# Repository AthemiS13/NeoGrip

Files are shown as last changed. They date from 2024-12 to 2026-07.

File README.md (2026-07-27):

# NeoGrip
Affordable custom controllers for Quest 2 and other VR headsets **purchased without original controllers**, or for those looking for open-source VR controllers. Designed using **ESP32** and [ALVR's API](https://github.com/alvr-org/ALVR "ALVR API") to emulate Quest controllers in **SteamVR**, this project makes headsets without controllers usable and accessible for VR enthusiasts on a budget.

> **Note:** The full, comprehensive documentation for this project is located in [Assets/dokumentace.pdf](Assets/dokumentace.pdf). Unfortunately, it is currently only available in the Czech language.

NeoGrip animation

## Motivation & Goals
The VR equipment market has a paradox: second-hand headsets like Meta Quest are very affordable, but they are often sold without original controllers, which are either unavailable or excessively expensive. NeoGrip was created to break this barrier, utilizing the hidden potential of incomplete VR setups. The goal is to provide a fully functional, open-source hardware and software solution that bridges the physical environment with SteamVR through affordable components.

## Hardware Requirements (Bill of Materials)
- **ESP32** Dev Module [Link](https://www.aliexpress.com/item/1005004879572949.html "Link")
- **TP4056** Charging Module [Link](https://www.aliexpress.com/item/1005007010409267.html "Link")
- **Joystick** KY-023 module [Link](https://www.aliexpress.com/item/1005006966359366.html "Link")
- **Buttons** (A, B, X, Y, Menu, Oculus) [Link](https://www.aliexpress.com/item/1005004254514071.html "Link")
- **End switches** Grab and Trigger (KW11-3Z-4-N) [Link](https://www.aliexpress.com/item/1005006260069918.html "Link")
- 3D-printed controller **parts** (STEP files available [here](https://github.com/AthemiS13/NeoGrip/tree/main/STEP-Files "here"))
 - **Regulator** Ultra Low Dropout voltage, 3.3V (RT9183-33GGF)
 - **Battery** 3.7V, 500mAh, Li-Po (You might be able to fit a bigger one) [Link](https://www.aliexpress.com/item/1005003156469047.html "Link")
  - **Transistor** Generic PNP or NPN transistor for haptic motor control.
  - **Haptic** Motor, 3.3V [Link](https://www.aliexpress.com/item/1005007550657082.html "Link")
  - **Screws, Springs, 2mm Shaft, Wires** 

## Hardware Design & Architecture
NeoGrip is designed with ergonomics and functionality mirroring the Meta Quest 2/3 controllers:
- **Core Controller:** ESP32 Dev Module (Dual-core Xtensa LX6 240MHz, Wi-Fi 2.4GHz) for minimal latency and high performance.
- **Controls:** Standard microswitches (A/X, B/Y, System, Joystick Click), highly reliable end switches KW11-3Z for Trigger and Grip (translated to 0.0/1.0 analog values for OpenXR), and KY-023 analog joysticks for X/Y movement.
- **Haptic Feedback:** Embedded 3.3V vibration motor driven by PWM via a PNP transistor for tactile responses from SteamVR.
- **Power Management:** Powered by a 3.7V 500mAh Li-Po battery providing ~6 hours of active playtime. Protected and charged via a TP4056 module (USB-C or Micro-USB). Includes an automatic deep sleep mode after 60 seconds of inactivity to save power, easily wakeable via the System button. An LDO RT9183 regulator provides stable 3.3V.

## Software Requirements
- [NeoGrip Proxy for Windows](https://github.com/AthemiS13/NeoGrip/releases) (download the latest `NeoGrip-Proxy.exe` release)
- [ALVR](https://github.com/alvr-org/ALVR "ALVR")
- [Arduino IDE](https://www.arduino.cc/en/software "Arduino IDE") or compatible ESP32 programming environment
- SteamVR
### Notes on Quest 2 Setup:
If you have purchased a Quest 2 without controllers that is logged out and factory resetted, bypassing the **initial setup** can be challenging. While this README focuses on the VRController project, instructions for bypassing the setup to enable hand tracking and unlock the headset can be provided on request.

## Software setup
### NeoGrip Proxy setup:
1. Go to the [latest NeoGrip release](https://github.com/AthemiS13/NeoGrip/releases) and download `NeoGrip-Proxy.exe`.
2. Start ALVR on the PC that will run the proxy.
3. Run `NeoGrip-Proxy.exe` and leave its console window open during your VR session.
4. Press the **System** button on each NeoGrip controller to connect it.

The proxy receives controller input on UDP port `9999`, sends haptic feedback on UDP port `8888`, and must be on the same local Wi-Fi network as the controllers.

> Windows SmartScreen may show a warning because the executable is not code-signed. If you downloaded it from the official NeoGrip GitHub release, select **More info** and then **Run anyway**.
### Pin Mapping (Right Controller Example)
- `GPIO 4`: System Button / Deep Sleep Wake (RTC GPIO)
- `GPIO 14`: Joystick Click
- `GPIO 16`: PWM Motor Output
- `GPIO 18`: B Button
- `GPIO 19`: Trigger (KW11-3Z)
- `GPIO 21`: A Button
- `GPIO 27`: Squeeze/Grip (KW11-3Z)
- `GPIO 34`: Joystick X-Axis (ADC 0-4095)
- `GPIO 35`: Joystick Y-Axis (ADC 0-4095)

### 3D Printed Chassis
Designed in Autodesk Fusion 360, printable via FDM. Recommended settings:
- **Material:** PLA (PETG optional for more durable triggers).
- **Layer Height:** 0.2mm for the main body, 0.15mm for finer button details.
- **Infill:** 65% Gyroid for high structural integrity and low weight.
- **Temperature:** 210°C for optimal layer adhesion.
- **Supports:** Tree-type supports recommended.

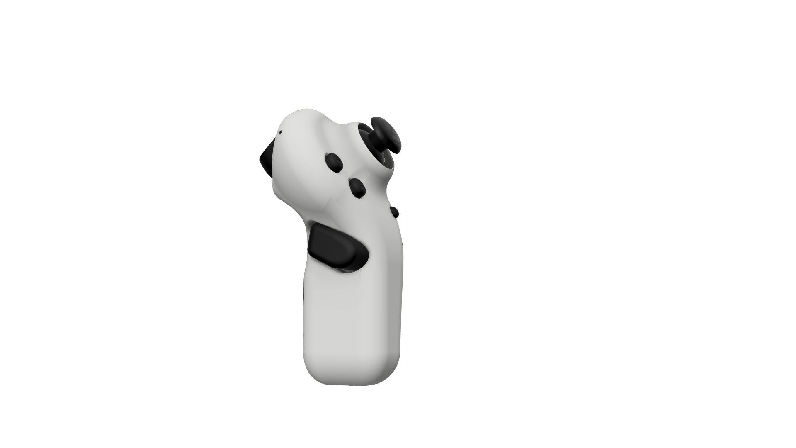
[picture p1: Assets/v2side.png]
Side


## How it Works
The architecture consists of the ESP32 hardware and a multi-threaded Python-based proxy server on the PC.

### 1. ESP32 Input Processing
Every 40ms, the ESP32 reads analog and digital inputs and formats them into a lightweight 15-character UDP broadcast packet (e.g., `L00010204720470`):
- **Char 1:** Side identifier (`L` or `R`).
- **Chars 2-6:** Button states (`A/X`, `B/Y`, `SYS`, `Trigger`, `Grip`) as `0` or `1`.
- **Chars 7-10:** Joystick X-axis analog value (`0000`-`4095`).
- **Chars 11-14:** Joystick Y-axis analog value (`0000`-`4095`).
- **Char 15:** Joystick Click state (`0` or `1`).

### 2. Python Proxy Server (`NeoGrip.py`)
To prevent blocking, the proxy server uses multiple threads:
- **Main Thread:** Receives UDP packets from the ESP32 on port `9999`.
- **ALVR Thread:** Forwards processed controller data to ALVR's REST API (`POST http://127.0.0.1:8082/api/set-buttons`).
- **WebSocket Thread:** Listens to `ws://localhost:8082/api/events` for haptic feedback triggers from SteamVR.
- **Start Signal Thread:** Broadcasts a "START" UDP packet to wake controllers from deep sleep.

### 3. ALVR and SteamVR Integration
The proxy translates raw values into standardized OpenXR paths (e.g., `/user/hand/left/input/trigger/value`), allowing the controllers to work natively with SteamVR. Instead of built-in positional tracking, the project relies on **Meta Quest Hand Tracking**. SteamVR binds the controller inputs directly onto the tracked hands in VR.

### 4. Haptic Feedback
The WebSocket thread captures haptic events, parsing the target controller (path), vibration duration, and amplitude. It maps amplitude (0.0-1.0) to PWM duty cycles (0-255) and converts the duration to milliseconds. It then sends a 7-character UDP packet back to the ESP32 on port `8888` (e.g., `R255100` -> Right controller, 255 duty cycle, 100ms duration).

### ALVR Configuration
For ALVR to accept inputs from the proxy server and track the controllers properly via headset cameras, you must adjust the following settings in ALVR:
1. **Presets tab:** Turn **off** "Hand tracking interaction" (we want to use the controller buttons, not gesture interactions).
2. **Headset tab:** Ensure the following are **enabled/on**:
   - `Controllers`
   - `Tracked`
   - `Multimodal tracking`
   - `Haptics`
3. Ensure that "SteamVR Input 2.0" and "Hand tracking interaction" (under Headset) are disabled.

> **Note:** A detailed visual guide for the ALVR configuration, alongside screenshots, is available in the [documentation PDF](Assets/dokumentace.pdf) as well as in the [Config](Config) directory.

### Running the System
1. Start SteamVR and ALVR. Verify configuration.
2. Run the proxy server via terminal:
   ```bash
   python NeoGrip.py
   ```
   The terminal will indicate that it's broadcasting the "START" signal.
3. Press the **System** button on your NeoGrip controllers to wake them up. They will connect to Wi-Fi and vibrate briefly upon a successful connection.
4. Put on your headset. Your controllers are now ready to use in SteamVR!
5. To stop, press `Ctrl+C` in the proxy console. The proxy will send a "STOP" signal, putting the controllers back to deep sleep.

## Performance & Testing
- **Latency:** The system provides extremely low latency, averaging under 50ms from physical button press to VR action, which is well within comfortable limits for fast-paced VR games.
- **Reliability:** The 2.4GHz Wi-Fi UDP connection provides robust data transmission with negligible packet loss (<1%). Missing packets are instantly superseded by the 25Hz refresh rate.
- **Battery Life:** ~6 hours of continuous playtime. The TP4056 module charges the 500mAh Li-Po battery at a rate of 1A, allowing a full recharge from 0 to 100% in approximately 45 minutes.

## Videos

### Finished Product Showcase
[**Watch the NeoGrip Finished Product Showcase on YouTube**](https://www.youtube.com/watch?v=nmFFR0dLkeE)

Watch the NeoGrip Finished Product Showcase (https://www.youtube.com/watch?v=nmFFR0dLkeE)

### 2024 Demo
[**Watch the NeoGrip 2024 Demo on YouTube**](https://youtu.be/AhS3Zu6njnE?si=yEACRPgUvw43rx8U)
Watch the video (https://youtu.be/AhS3Zu6njnE?si=yEACRPgUvw43rx8U)

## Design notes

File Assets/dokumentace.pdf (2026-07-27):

## Gymnázium a Jazyková škola s právem státní jazykové zkoušky Zlín

# NeoGrip

## Vývoj softwarového proxy serveru pro integraci alternativního hardwaru do platformy SteamVR

### Jakub Chmelař

2026

# Poděkování

Tímto bych rád upřímně poděkoval svému pedagogovi, panu učiteli Michalovi Miklášovi, za obětavou pomoc, cenné konzultace a významné prohloubení mých vědomostí v programovacím jazyce Python, které byly pro zdárné dokončení této práce klíčové. Dále bych chtěl vyjádřit své poděkování komunitě vývojářů softwaru ALVR za jejich vstřícnost a skvělou spolupráci v průběhu celého vývoje projektu.

# Anotace

Tato práce se detailně zabývá návrhem a implementací projektu NeoGrip. Cílem systému je vytvořit funkční spojovací článek mezi hardwarovými ovladači, postavenými na mikrokontroleru ESP32, a prostředím virtuální reality SteamVR. Pro distribuci vstupů a přenos prostorových dat je využíván otevřený software ALVR. Ačkoliv projekt zahrnuje i konstrukci fyzického elektronického obvodu, primární pozornost a stěžejní téma této práce tvoří softwarová vrstva. Jejím jádrem je návrh a vývoj vlastního proxy serveru vybudovaného v jazyce Python. Právě tento programovací blok představuje ústřední prvek řešení, který získává nezpracovaná data uživatelského hardwaru a v reálném čase je transformuje do rozhraní virtuálního prostředí.

# Klíčová slova

virtuální realita; SteamVR; ESP32; proxy server; ALVR; Python; hardware

# Obsah

Seznam obrázků | 5
Seznam tabulek | 6
1 Úvod | 7
2 Motivace a cíle projektu | 8
3 Teoretická východiska | 9
4 Hardwarový návrh | 11
5 Činnost a logika mikrokontroleru ESP32 | 15
6 Softwarová vrstva (proxy server) | 18
7 Integrace se softwarem ALVR a platformou SteamVR | 23

8 Instalace a spuštění | 28
9 Testování a výsledky | 30
10 Závěr | 33
Bibliografie | 34

# Seznam obrázků

1 | Pohled na ovladač NeoGrip ze strany | | 7

2 Vývojová deska s mikrokontrolerem ESP32 | 10 3 Schéma rozložení pinů ESP32 DevKit V1 | 11 4 Vnitřní uspořádání elektronických komponent v programu Fusion 360 . . . 12 5 Detail ovladače NeoGrip s viditelnými ovládacími prvky | 13 6 Návrh celého ovladače NeoGrip v programu Fusion 360 | 14 7 Model hlavního těla ovladače připravený pro 3D tisk | 15 8 Pohled na zadní stranu ovladače NeoGrip | 15 9 Krok 1: Nastavení v záložce Presets | 25 10 Krok 2: Nastavení v záložce Headset | 26 11 Krok 3: Dodatečné konfigurace | 27

# Seznam tabulek

### 1 Přiřazení pinů mikrokontroleru ESP32 (pravý ovladač) | 12 2 Formát odesílaného UDP paketu | 16 3 Přehled vláken proxy serveru | 18

4 | Proces zpracování haptické zprávy z ALVR | | 21

### 5 Vstupní cesty ALVR API (levý ovladač) | 24

# 1 Úvod

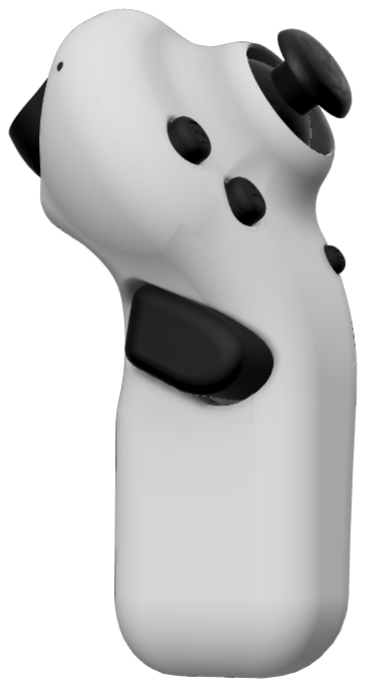
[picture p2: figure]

obrázek 1: Pohled na ovladač NeoGrip ze strany

Projekt NeoGrip představuje inovativní architekturu, jež prostřednictvím proxy serveru napsaného v jazyce Python efektivně propojuje cenově dostupný mikrokontroler ESP32 se systémem SteamVR. Ačkoliv je pro komplexní pochopení problematiky nutné v práci představit všechny vrstvy tohoto fungujícího celku, hlavním těžištěm textu a primárním zaměřením je vývoj zmíněného proxy serveru v jazyce Python. Plynulý a spolehlivý tok dat zajišťuje integrace softwarového nástroje ALVR, což otevírá nové možnosti alternativního řízení a ovládání ve virtuálním prostředí.
Trh s periferními zařízeními pro virtuální realitu je velmi omezený: zatímco náhlavní soupravy jsou stále dostupnější, ceny originálních ovladačů zůstávají nepřiměřeně vysoké nebo jsou tyto periferie zcela nedostupné. Projekt NeoGrip si klade za cíl tuto bariéru odstranit cestou otevřeného hardwarového a softwarového řešení postaveného na všeobecně dostupných komponentech.
Dokument je strukturován tak, aby čtenáře systematicky provedl od hardwarového návrhu přes firmwarovou implementaci až ke klíčové softwarové vrstvě. Závěrečné kapitoly pak popisují integraci s ekosystémem ALVR a SteamVR, postup instalace a výsledky praktického testování.

# 2 Motivace a cíle projektu

## 2.1 Problém dostupnosti VR ovladačů

Současný trh s vybavením pro virtuální realitu se potýká se zajímavým paradoxem. Náhlavní soupravy z druhé ruky, jako je populární rodina Meta Quest, lze pořídit za velmi příznivé ceny. Jejich zásadním úskalím je nicméně to, že se často prodávají samotné, tedy bez originálních ovladačů. Samostatné originální ovladače jsou buď zcela nedostupné, nebo jejich pořizovací cena výrazně převyšuje hodnotu samotné soupravy. Mnoho uživatelů se tak dostává do slepé uličky, kdy levnou a zcela funkční soupravu nemohou používat ke svému primárnímu účelu.
Hlavní motivací tohoto projektu bylo odstranit tuto bariéru a využít skrytý potenciál nekompletních souprav pro virtuální realitu. Cílem bylo navrhnout, sestavit a naprogramovat cenově dostupné hardwarové ovladače s otevřeným designem ve formátu zařízení Meta Quest 2, jež by propojily fyzické prostředí s prostředím virtuálním prostřednictvím systému SteamVR.

## 2.2 Cíle projektu

Během realizace byly sledovány následující cíle:

- Přístupná hardwarová architektura: Navrhnout logický obvod s mikrokontrolerem ESP32 jako klíčovou řídicí jednotkou. Architektura měla obsahovat všechny ovládací prvky původní periferie Meta Quest 2 (analogové páčky s proklikem, přední a boční tlačítka, haptická odezva). Nedílnou součástí je také efektivní správa napájení zajištěná integrovaným obvodem TP4056 a implementace režimu hlubokého spánku při nečinnosti.
- Proxy server: Vytvořit stabilní softwarový můstek zprostředkující datový převod zasílaných stisků a analogových hodnot z ESP32 odesílaných bezdrátově skrze protokol UDP směrem do SteamVR.
- Integrace s ALVR: Pro převod nezpracovaných dat do systémových akcí rozeznatelných ekosystémem SteamVR bylo nutné využít aplikační rozhraní projektu ALVR. Zprostředkující proxy server v jazyce Python tak slouží jako neviditelná vrstva tvořící softwarový klíč pro danou architekturu.

## 2.3 Přínos a uplatnění projektu

Jak ukáže technická sekce maturitní práce o vývoji NeoGripu, spojení hardwarového obvodu ovládaného platformou ESP32 a softwarového překladače dat se ukázalo jako velice úspěšné a vysoce uplatnitelné řešení. Výsledný systém je plně funkční, jeho celkové náklady na výrobu jednoho páru ovladačů nepřesahují 600 Kˇc, a veškerý zdrojový kód spolu s výkresovou dokumentací je volně dostupný jako otevřený projekt[8].

# 3 Teoretická východiska

## 3.1 Virtuální realita a její ekosystém

Virtuální realita (VR) je technologie umožňující uživateli plné ponoření do počítačem generovaného trojrozměrného prostředí prostřednictvím náhlavní soupravy. Klíčovými vlastnostmi moderní virtuální reality jsou sledování polohy hlavy v šesti stupních volnosti¹ ,
prostorový zvuk a interakce prostřednictvím ručních ovladačů snímajících pohyb a stisk tlačítek.

## 3.2 Platforma SteamVR a standard OpenXR

SteamVR je softwarová platforma společnosti Valve Corporation, jež tvoří standardizovaný mezičlánek mezi VR aplikacemi a hardwarem různých výrobců. SteamVR implementuje standard OpenXR[4]²
, jenž zavádí jednotný způsob popisu vstupů ovladačů pomocí cest. Například cesta /user/hand/left/input/trigger/value jednoznačně identifikuje analogovou hodnotu spouště levého ovladače.
Pro projekt NeoGrip je tato vrstva zásadní: díky standardizovanému popisu vstupů lze vlastní firmwarová data přeložit do formátu srozumitelného pro libovolnou VR aplikaci kompatibilní s SteamVR, aniž by bylo nutné upravovat samotné herní tituly.

## 3.3 Software ALVR

ALVR (Air Light VR) je otevřený software, jenž zprostředkovává bezdrátový přenos VR obrazového toku z osobního počítače do mobilní náhlavní soupravy na platformě Android. V kontextu tohoto projektu do zařízení Meta Quest 2.[1]
Kromě přenosu obrazu disponuje ALVR aplikačním rozhraním:
- REST API naslouchající na portu 8082, přes které lze vkládat vstupní události ovladačů metodou POST na koncový bod /api/set-buttons.
- WebSocket na adrese ws://localhost:8082/api/events, přes který ALVR v reálném čase vysílá události haptické odezvy pocházející z SteamVR.

Tato dvě rozhraní tvoří základ obousměrné komunikace projektu NeoGrip s ekosystémem SteamVR a jsou podrobněji popsána v kapitole 7.

## 3.4 Komunikační protokol UDP

Pro přenos dat mezi ovladačem ESP32 a proxy serverem byl zvolen protokol UDP[11]. Na rozdíl od protokolu TCP nezaručuje UDP doručení každého paketu ani jejich pořadí,

1Šest stupňů volnosti (anglicky six degrees of freedom, zkr. 6DoF) označuje kombinaci tří translačních (posun v osách X, Y, Z) a tří rotačních pohybů, které je systém schopen sledovat v reálném čase. 2OpenXR je otevřený mezioborový standard definovaný společností Khronos Group, který sjednocuje aplikační rozhraní pro vývoj VR a rozšířené reality (AR).

avšak jeho klíčovou předností je minimální latence způsobená absencí potvrzovacích mechanismů.[3] V kontextu ovladače pro virtuální realitu, kde je okamžitá odezva nadřazena absolutní spolehlivosti přenosu, představuje volba protokolu UDP optimální kompromis. Ztráta ojedinělého paketu způsobí pouze krátkodobé zdržení a je automaticky překryta dalším paketem přijatým po 40 ms.

## 3.5 Mikrokontroler ESP32

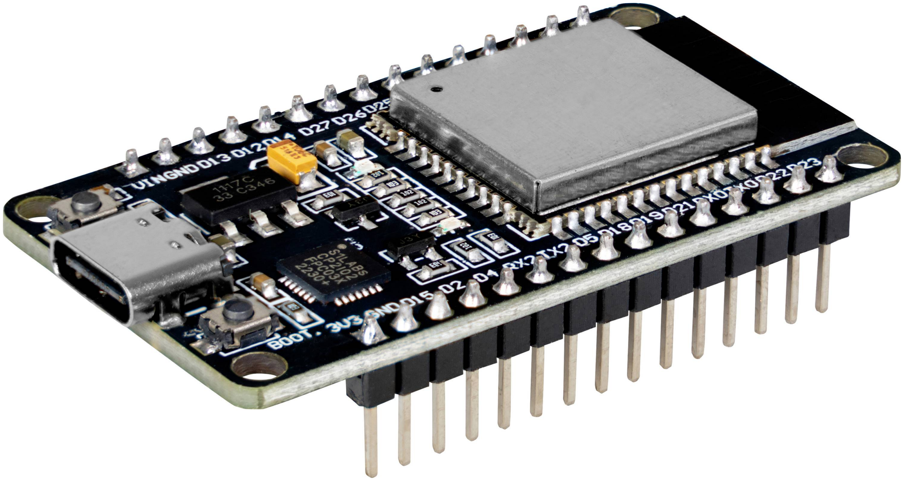
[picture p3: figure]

obrázek 2: Vývojová deska s mikrokontrolerem ESP32

ESP32 je rodina systémů na čipu vyvinutá společností Espressif Systems.[2] Klíčovými vlastnostmi relevantními pro tento projekt jsou:

- dvoujádrový procesor Xtensa LX6 s taktovací frekvencí až 240 MHz,
- integrovaný Wi-Fi modul standardu 802.11 b/g/n v pásmu 2.4 GHz,
- dvanáctibitový analogově-digitální převodník (ADC) s rozsahem 0 až 4095 pro snímání analogových hodnot páčky,
- podpora pulzně-šířkové modulace (PWM)[14] pro řízení haptického motoru,
- režim hlubokého spánku s příkonem řádově v jednotkách µA.

# 4 Hardwarový návrh

Realizace fyzického ovladače vyžadovala pečlivý výběr komponent, které by splňovaly přísné požadavky na minimální odezvu, dostatečný výpočetní výkon pro zpracování síťového provozu a zároveň udržely celkové pořizovací náklady na rozumném minimu. Rozložení ovládacích prvků navíc přímo vychází z ergonomie a architektury ovladačů Meta Quest 2, čímž je zaručena pro uživatele intuitivní ovladatelnost.

## 4.1 Řídicí jednotka ESP32

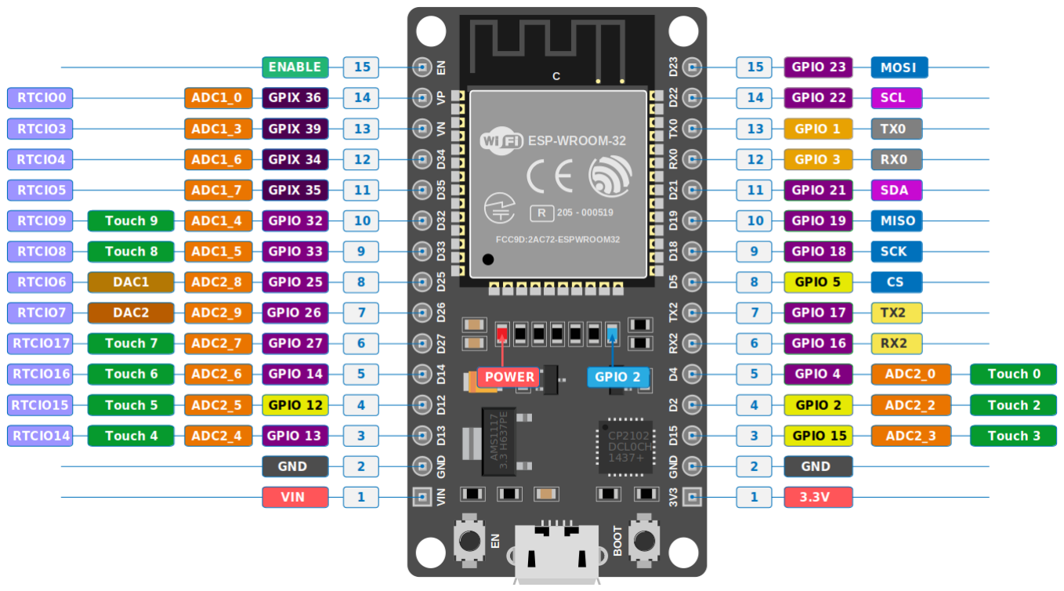
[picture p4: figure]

obrázek 3: Schéma rozložení pinů ESP32 DevKit V1

Jako řídicí mozek celého ovladače byl zvolen mikrokontroler ESP32 ve verzi Dev Module. Tato platforma se vyznačuje vysokým výkonem (dvoujádrový procesor) a především integrovaným Wi-Fi modulem pracujícím v pásmu 2.4 GHz. Přítomnost Wi-Fi adaptéru je kritická, jelikož veškerá data o stisku tlačítek a hodnotách analogových páček jsou z ESP32 odesílána vzduchem prostřednictvím rychlého protokolu UDP do nadřazeného proxy serveru na osobním počítači (v neměnném intervalu 40 ms).
Přiřazení vstupních a výstupních pinů mikrokontroleru pro pravý ovladač je shrnuto v tabulce 1.

## 4.2 Napájení a správa energie

Ovladač pro virtuální realitu představuje mobilní zařízení, jež nevyhnutelně vyžaduje spolehlivý zdroj napájení. NeoGrip je poháněn lithio-polymerovým (Li-Po) akumulátorem s kapacitou 500 mA h a nominálním napětím 3.7 V. Výsledná doba provozu na jedno nabití se pohybuje okolo šesti hodin.
O bezpečnost při nabíjení a vybíjení článku se stará modul s integrovaným obvodem TP4056, dostupný ve variantách s konektorem USB-C i starším Micro-USB. Ten baterii jednak nabíjí bezpečným proudem a jednak ji odpojí v případě podbití, čímž ji chrání před zničením. Z hlediska regulace provozního napětí zajišťuje pro čip ESP32 nutných 3.3 V systémový LDO regulátor s velmi nízkým úbytkem napětí (typ RT9183). Významným softwarovým prvkem ochrany baterie je implementace režimu hlubokého spánku. Ovladač do něj automaticky přechází po šedesáti sekundách nečinnosti, pokud od počítače nepřijme úvodní signál "START", případně okamžitě po ukončení relace, kdy je odeslán signál "STOP". Probuzení je poté řešeno hardwarově stiskem vyhrazeného systémového tlačítka, které je na desce připojeno k tzv. probouzecímu pinu (RTC GPIO). Jeho ukostřením (sepnutím k zemi) dojde k přerušení klidové činnosti koprocesoru s extrémně nízkou spotřebou, čímž se hlavní jádro CPU znovu bezpečně nastartuje, provede standardní zaváděcí proces (boot) a obnoví Wi-Fi spojení.

tabulka 1: Přiřazení pinů mikrokontroleru ESP32 (pravý ovladač)

Pin GPIO | Periferie | Funkce
4 14 16 18 19 21 27 34 35 | Tlačítko SYS Tlačítko JOYCLK Motor (PWM) Tlačítko B Tlačítko TRIG Tlačítko A Tlačítko SQZ Směrová páčka (osa X) Směrová páčka (osa Y) | Systémové tlačítko, zároveň vstup probuzení ze spánku Stisk analogové páčky Výstup PWM pro haptický vibrační motor Akční tlačítko B Spoušť (koncový spínač KW11-3Z) Akční tlačítko A Boční úchop (koncový spínač KW11-3Z) Analogový vstup ADC, rozsah 0–4095 Analogový vstup ADC, rozsah 0–4095

## 4.3 Propojení komponent a elektrické schéma

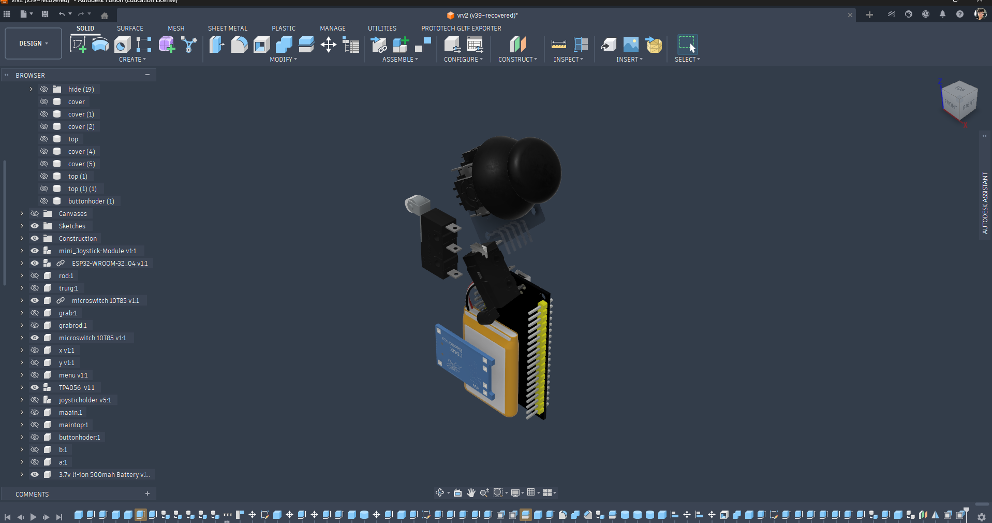
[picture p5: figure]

obrázek 4: Vnitřní uspořádání elektronických komponent v programu Fusion 360

Elektrické schéma projektu NeoGrip bylo navrženo s ohledem na minimalizaci komponent a využití vnitřních funkcí mikrokontroleru ESP32 (např. interní pull-up rezistory). Klíčové bloky zapojení zahrnují:
- Vstupní blok: Všech šest digitálních tlačítek je zapojeno přímo proti zemi (GND) s aktivovaným softwarovým pull-up rezistorem v kódu firmwaru. Toto řešení zjednodušuje zapojení obvodu a eliminuje potřebu externích součástek.

- Analogový blok: Potenciometry analogových páček jsou napájeny stabilním napětím 3.3 V z LDO regulátoru. Výstupní napětí jezdců je přivedeno na piny kanálu ADC1 jednotky ESP32, čímž je zaručeno přesné měření i při aktivním Wi-Fi vysílání (na rozdíl od ADC2, který při vysílání Wi-Fi nefunguje).
- Haptický blok: Vzhledem k proudovému odběru vibračního motorku přesahujícímu 100 mA je motor spínán přes tranzistor. Do báze tranzistoru je přiveden signál PWM přes omezovací rezistor 1 kΩ. Paralelně k motorku je zapojena ochranná dioda pro potlačení napěťových špiček při spínání indukční zátěže.

Vzhledem k prostorovým omezením vnitřní dutiny ovladače a snaze o minimalizaci nákladů je veškerá elektronika propojena pouze pomocí vodičů a pájecích bodů.

## 4.4 Vstupní a výstupní periferie

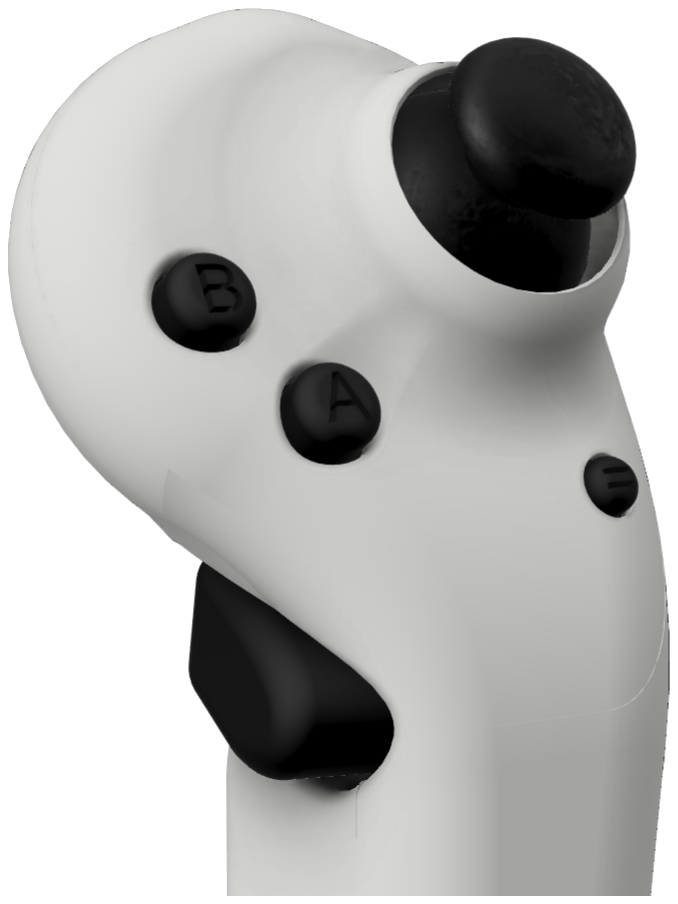
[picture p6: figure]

obrázek 5: Detail ovladače NeoGrip s viditelnými ovládacími prvky

Ovladač replikuje všechny vstupní metody, které standardně nalezneme u profesionálních řešení. Mezi použitými periferiemi jsou:

- Tlačítka: Standardní mikrospínače zastupující akční tlačítka (A/X, B/Y), systémové tlačítko a odpružené stisknutí páčky.
- Spouště: Pro detekci stisku ukazováčku a horního úchopu slouží vysoce spolehlivé koncové spínače (model KW11-3Z). Pro maximální zjednodušení celého systému, snížení složitosti zapojení i celkových výrobních nákladů tento projekt nevyužívá plně analogové spouště. Místo toho jsou tyto digitální stisky koncových spínačů softwarově převáděny na binární analogové hodnoty (0,0 nebo 1,0), aby přesně vyhovovaly standardu OpenXR.
- Analogové páčky: Směrový pohyb v osách X a Y zabezpečují moduly KY-023. Jde o dvouosé potenciometry odesílající do jednotky ESP32 analogové napětí nabývající digitálních hodnot 0 až 4095 v každé z os.
- Haptická odezva: Je řešena tradičním vibračním motorkem (napájeným napětím 3.3 V), jehož otáčky zprostředkovaně reguluje mikrokontroler prostřednictvím pulzně-šířkové modulace (PWM). Výkonový obvod motorku je spínán PNP tranzistorem, který slouží jako výkonový spínač a chrání pin ESP32 před překročením povolených limitů proudu.

## 4.5 Mechanická konstrukce a 3D tisk

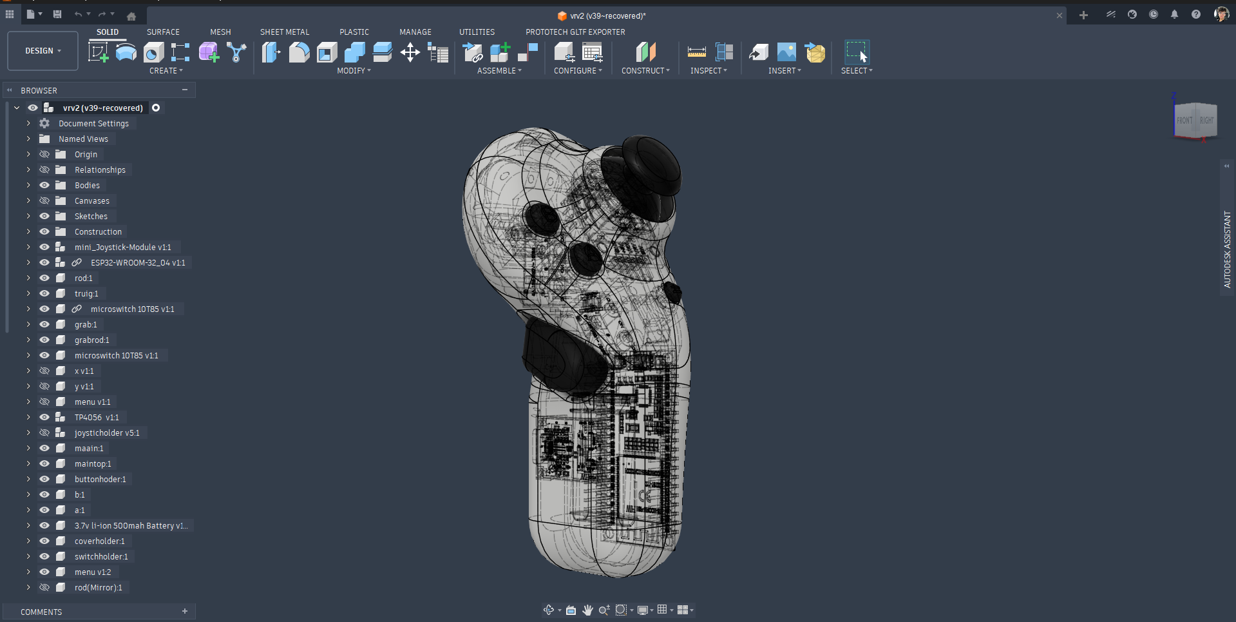
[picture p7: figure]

obrázek 6: Návrh celého ovladače NeoGrip v programu Fusion 360

Kryt ovladače byl kompletně vymodelován v softwaru Autodesk Fusion 360. Při návrhu byl kladen důraz na ergonomii: rozložení a tvar ovládacích prvků přímo vychází z profesionálních ovladačů Meta Quest 3, takže je práce s ovladačem pro uživatele intuitivní.
Finalizovaný model byl následně vytištěn technologií FDM³
(metoda taveného vlákna).
Jako hlavní materiál byl zvolen PLA (kyselina polymléčná)[12] pro svou tvarovou stálost a spolehlivost, ačkoliv pro mechanicky namáhané díly spouště by bylo možné v budoucnu uvažovat o odolnějším materiálu PETG.
Samotný tisk probíhal s následujícím nastavením, které zajišťuje optimální rovnováhu mezi pevností a estetickou kvalitou povrchu:
- Výška vrstvy: 0.2 mm pro hlavní tělo, 0.15 mm pro jemnější detaily ovládacích tlačítek.
- Vnitřní výplň: 65 % vzoru „Gyroid“, jenž poskytuje vysokou strukturální pevnost ve všech směrech při zachování nízké hmotnosti.
- Teplota trysky: 210 ∘C pro optimální adhezi vrstev.
- Podpěry: Byly generovány podpory stromového typu, které byly následně odstraněny.

Kryt se skládá z několika odděleně tištěných dílů, které jsou sestaveny třecí vazbou, pružinami, hřídeli o průměru 2 mm a lepidlem. Šrouby jsou použity výhradně pro uchycení koncových spínačů spouště a úchopu. Spoušť i boční úchop využívají pružnou mechaniku s koncovým spínačem, která zajistí snímač při stisknutí a vrátí jej do výchozí polohy po uvolnění.

3FDM (Fused Deposition Modeling) je metoda 3D tisku, při níž je termoplastický materiál vytlačován z rozpálené trysky a kladen po vrstvách na tiskovou podložku.

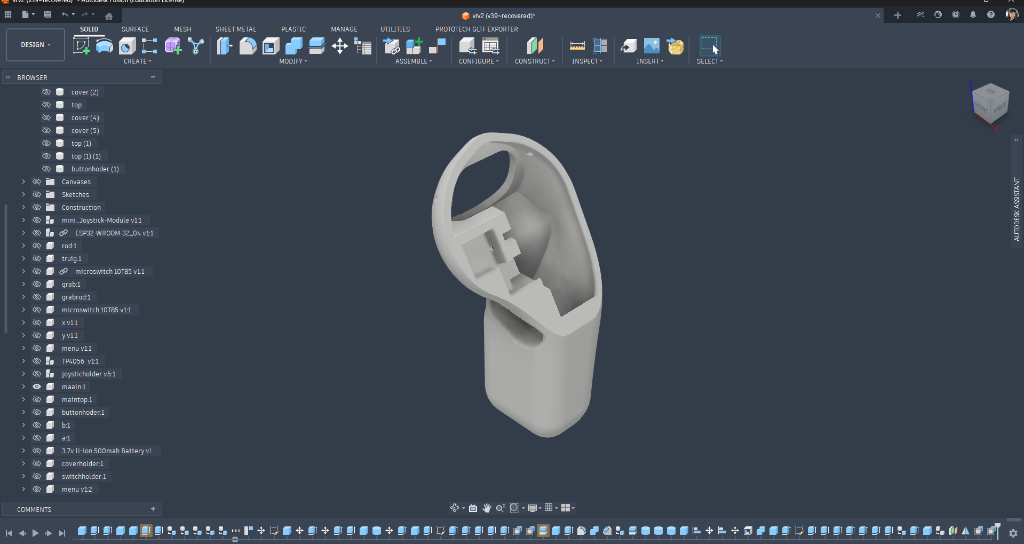
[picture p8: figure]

obrázek 7: Model hlavního těla ovladače připravený pro 3D tisk

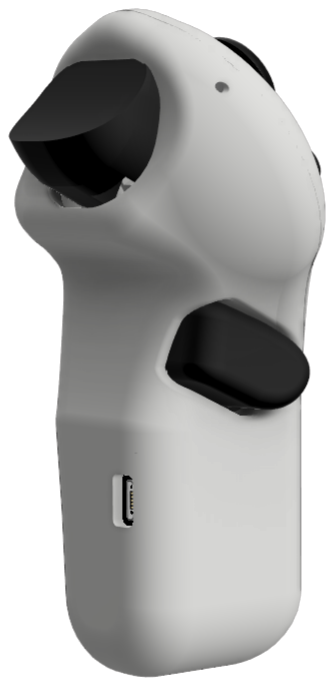
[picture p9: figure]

obrázek 8: Pohled na zadní stranu ovladače NeoGrip

# 5 Činnost a logika mikrokontroleru ESP32

Kompletní firmware pro řídicí jednotku ESP32 byl vyvíjen v programovacím jazyce C++ s využitím profesionálního vývojového prostředí PlatformIO[10]. Toto moderní rozšíření pro editor kódu umožnilo efektivní správu použitých knihoven a pohodlné sestavování i následné nahrávání výsledného programu.
Řídicí logika mikrokontroleru ESP32 zajišťuje veškeré nezbytné procesy pro spolehlivou komunikaci s proxy serverem, zpracování uživatelských vstupů a efektivní správu napájení. Z hlediska fungování lze činnost mikrokontroleru rozdělit do čtyř základních fází: inicializace, protokol vyčkávání, odesílání stavu periferie a příjem haptické zpětné vazby.

## 5.1 Inicializace a konfigurace

Po zapnutí zařízení mikrokontroler automaticky zahájí proces připojování k předem definované síti Wi-Fi. Pokud se připojení nezdaří v určeném časovém limitu, systém se z bezpečnostních důvodů restartuje a pokusí se o spojení znovu. Po úspěšném připojení dojde k inicializaci všech propojených vstupních a výstupních pinů, přes které jsou snímána tlačítka a analogová páčka, a k zajištění komunikace s haptickým motorem prostřednictvím pulzně-šířkové modulace. Na závěr inicializační fáze vydá ovladač krátký vibrační signál upozorňující na úspěšné spojení se sítí.

## 5.2 Protokol vyčkávání na spuštění

Aby nedocházelo ke zbytečnému vybíjení baterie v době, kdy proxy server na nadřazeném počítači ještě neběží, aktivuje mikrokontroler po úvodní konfiguraci takzvaný protokol vyčkávání. V tomto stavu aktivně naslouchá příchozím UDP paketům a očekává přijetí inicializačního řetězce "START". Pokud tento signál nepřijde v rámci jedné minuty, zařízení se automaticky přepne do režimu hlubokého spánku pro minimalizaci energetických ztrát. Po obdržení signálu je ovladač plně probuzen, což opět potvrdí jemnou vibrací, a dále přechází do hlavní provozní smyčky.

## 5.3 Zpracování vstupů a odesílání dat

Klíčovým úkolem mikrokontroleru je v pravidelných intervalech (nastavených na 40 ms) snímat aktuální stav všech hardwarových prvků. Analogové hodnoty, měřící výchylky obou os analogové páčky, nabývají číselných hodnot v rozsahu od 0 do 4095. Stisky tlačítek jsou snímány jako binární stavy (stisknuto / uvolněno).
Všechny tyto nasbírané informace jsou následně sloučeny a zformátovány do jednotného textového paketu o velikosti 15 znaků. Struktura tohoto paketu je pro správnou interpretaci na straně proxy serveru striktně daná a rozvržena dle tabulky 2.

Ukázka: Následující případ demonstruje datový paket z levého ovladače během stisku hlavní spouště (ostatní prvky a páčka jsou v klidovém stavu):
L00010204720470

Strana
(Levá)

Tlačítka
(X, Y, SYS, spoušť, úchop)

Osa X
(Střed)

Osa Y
(Střed)

Klik
páčky

tabulka 2: Formát odesílaného UDP paketu

Pozice | Délka | Obsah
1 2–6 7–10 11–14 15 | 1 znak 5 znaků 4 znaky 4 znaky 1 znak | Identifikátor strany (L nebo R) Stavy tlačítek A/X, B/Y, SYS, spoušť, úchop (0/1) Analogová hodnota osy X páčky (0000–4095) Analogová hodnota osy Y páčky (0000–4095) Stisk analogové páčky (0 nebo 1)

Výsledný textový řetězec je odeslán protokolem UDP ve formě všesměrového vysílání (tzv. sdílený režim). To znamená, že paket je vypuštěn do celé lokální sítě, čímž odpadá nutnost znát přesnou IP adresu koncového počítače s běžícím proxy serverem.

## 5.4 Příjem a haptická odezva

Kromě odesílání dat mikrokontroler v každém kroku také kontroluje, zda mu z počítače nebyl odeslán povel k vykonání haptické odezvy či signál "STOP" k ukončení provozu. Povel k aktivaci vibračního motorku v sobě nese informace o intenzitě a čase v milisekundách, po jaký má vibrace trvat. Díky promyšlené logice navíc nedochází při provádění delších vibrací k přerušení komunikace — odpočítávání času probíhá na pozadí a ovladač tak může i během vibrování nadále kontinuálně číst hodnoty páčky a tlačítek a odesílat je k zpracování.

# 6 Softwarová vrstva (proxy server)

Proxy server tvoří ústřední prvek softwarové architektury projektu NeoGrip. Původní návrh tohoto celého projektu však paradoxně s přítomností jakéhokoliv softwarového počítačového prostředníka nepočítal. Prvotním plánem bylo vynechat samotný proxy server na platformě osobního počítače tak, aby plně vybavené ovladače ESP32 obstaraly komplexní obousměrnou komunikaci přímo s rozhraním ALVR a SteamVR.
Během aktivního vývoje se nicméně velmi záhy ukázalo, že navzdory dvěma jádrům nedisponuje mikrokontroler dostatečným výpočetním výkonem na to, aby plynule vyřizoval masivní HTTP POST požadavky, udržoval plně aktivní WebSocket spojení a do toho všeho ještě bez jakékoliv nechtěné latence vyhodnocoval stisky vlastních hardwarových tlačítek v přísném závazku jednoho odeslaného stavu každých 40 ms.
Z tohoto důvodu byla vytvořena odlehčující cesta: fyzický ovladač nyní vysílá rychlé a odlehčené UDP pakety s nezpracovanými daty na PC, kde celou složitou síťovou a překladatelskou logiku převezme skript NeoGrip.py napsaný v jazyce Python. Ten tedy výborně plní funkci zprostředkovávajícího článku mezi fyzickým ovladačem (ESP32) a prostředím virtuální reality SteamVR. Přijímá nezpracované datagramy z ovladačů, dekóduje je, transformuje do standardizovaného formátu aplikačního rozhraní ALVR a zpětně odesílá příkazy pro haptickou odezvu.

## 6.1 Architektura a souběžné zpracování

Aby mohl proxy server obsluhovat více datových toků současně bez vzájemného blokování, je navržen jako vícevláknová aplikace (viz tabulku 3). Každý z dílčích procesů běží v samostatném vláknu. Předávání dat pro odeslání do virtuální reality zajišťuje fronta Queue[9] ze standardní knihovny Python, zatímco pro bezpečnou manipulaci se sdílenými stavovými proměnnými (např. seznam připojených ovladačů) se využívá zámek threading.Lock()[9].

tabulka 3: Přehled vláken proxy serveru

Vlákno | Funkce
Hlavní vlákno alvr_thread ws_thread start_signal_thread | Příjem UDP paketů z ESP32 a volání process_packet() Odesílání zpracovaných dat na ALVR REST API Naslouchání haptickým událostem přes WebSocket Všesměrové vysílání signálu "START" při spuštění

## 6.2 Inicializace soketů a signál spuštění

Po spuštění skriptu jsou inicializovány dva UDP sokety: sock_receive pro příjem dat od ovladačů na portu 9999 s nastaveným časovým limitem pro plynulé zachytávání signálů přerušení klávesovou zkratkou (Ctrl+C). Dále sock_send s povoleným všesměrovým vysíláním pro odesílání signálů a haptické zpětné vazby na port 8888.
Vlákno start_signal_thread opakovaně odesílá všesměrový paket "START" do celé lokální sítě, čímž informuje ovladače o připravenosti serveru. Čtení stavu připojených ovladačů je chráněno vláknovým zámkem state_lock. Vysílání se zastaví, jakmile se připojí oba ovladače, nebo po patnácti sekundách od připojení prvního ovladače — proxy server poté pokračuje v jednoovladačovém režimu.
1 | def send_startup_signal () :
2 | global connected_controllers , last_connection_time

3
4 | while True :
5 | with state_lock :
6 | num_connected = len( connected_controllers )
7 | time_since_last = time . time () - last_connection_time

8
9 | if num_connected == 2:
10 | break

11
12 | if num_connected == 1 and time_since_last > 15:
13 | break

14
15 | try:
16 | sock_send . sendto ( b" START ", ( broadcast_ip ,
| pc_to_esp_port ) )
17 | time . sleep (0.5)
18 | except Exception as e :
19 | print ( f"[ ERROR ] Failed to send START : {e}")
20 | time . sleep (0.5)

ukázka kódu 1: Funkce send_startup_signal() — všesměrové vysílání signálu "START"

## 6.3 Zpracování příchozích paketů a práce s IP adresami

Ústřední funkcí pro zpracování dat je process_packet(), jejíž zkrácená podoba je znázorněna v ukázce kódu 2. Fyzický ovladač posílá svá strukturovaná UDP data všesměrově z neznámé adresy. Proxy server proto nepracuje se statickými IP adresami. Místo toho z každého přijatého datagramu dynamicky a průběžně extrahuje zdrojovou IP adresu koncových ovladačů. Ty si bezpečně zakládá do své aplikační paměti (controller_ips), aby mohl v pozdějších fázích zpětně přesně doručit jednosměrné pakety obsahující haptickou odezvu či signál k ukončení.
Kromě uložení adresy funkce ověří délku paketu na přesně 15 znaků, identifikuje stranu ovladače, extrahuje binární a analogové hodnoty vstupů a sestaví z nich seznam objektů kompatibilních s rozhraním ALVR. Tato data jsou vložena do fronty state_queue.

1 | def process_packet ( packet , addr = None ) :
2 | global connected_controllers , last_connection_time ,
controller_ips
3 | try:
4 | if len( packet ) != 15:
5 | return

6
7 | controller_id = packet [0] | # 'L' nebo 'R'

8
9 | with state_lock :
10 | if controller_id not in connected_controllers :
11 | connected_controllers . add ( controller_id )
12 | if addr :
13 | controller_ips . add ( addr [0])
14 | last_connection_time = time . time ()

15
16 | button_1 = int( packet [1]) | # A/X
17 | button_2 = int( packet [2]) | # B/Y
18 | button_SYS = int( packet [3])
19 | button_TRIG = int( packet [4])
20 | button_SQZ = int( packet [5])
21 | joyX = int( packet [6:10])
22 | joyY = int( packet [10:14])
23 | button_JOYCLK = int( packet [14])

24
25 | ...
26 | # Sestaven í ALVR pole `data ` na zaklade `hand_path `
27 | ...
28 | state_queue . put ( data )
29 | except ValueError as e :
30 | print ( f"[ ERROR ] Packet decode error : {e}")

ukázka kódu 2: Zpracování paketu ve funkci process_packet()

Analogové hodnoty páčky (rozsah 0 až 4095) jsou normalizovány na rozsah −1,0 až +1,0 dle vzorce 1, kde 2047 odpovídá klidové poloze páčky:

vnorm =

vraw − 2047
2047

(1)

## 6.4 Komunikace s rozhraním ALVR

Vlákno alvr_thread opakovaně vyvolává funkci send_to_alvr(). Ta vybírá zpracovaná data z fronty state_queue a HTTP metodou POST je odesílá na lokální adresu http://127.0.0.1:8082/api/set-buttons. Požadavek obsahuje specifickou bezpečnostní HTTP hlavičku X-ALVR: true. Tato hlavička je nedílným požadavkem (sloučeným z ochranné politiky CSRF — Cross-Site Request Forgery) ze strany aktuální verze ALVR API[13], bez které cílový server z bezpečnostních důvodů okamžitě stornuje navázané spojení. Celé tělo je posléze baleno do formátu JSON. Při odesílání je definován krátký časový limit o délce 0.1 s, který zabraňuje zablokování vlákna v případě nedostupnosti ALVR.

1 | headers = {"X- ALVR ": " true ", " Content - Type ": " application / json "}
2 | alvr_url = " http ://127.0.0.1:8082/ api/set - buttons "

3
4 | def send_to_alvr () :
5 | while True :
6 | try:
7 | data = state_queue . get ()
8 | requests . post ( alvr_url , headers = headers , json = data ,
| timeout =0.1)
9 | except Exception as e :
10 | print ( f"[ ERROR ] ALVR request failed : {e}")

ukázka kódu 3: Odeslání dat na ALVR API

## 6.5 Zpracování haptické odezvy přes WebSocket

Pro příjem haptických událostí ze SteamVR prostřednictvím ALVR udržuje server trvalé WebSocket spojení na adrese ws://localhost:8082/api/events. Příchozí textové zprávy jsou formátovány jako strukturované objekty JSON, ze kterých systém detekuje události patřící haptické odezvě. Taková událost v sobě nese aplikační cestu (identifikující stranu ovladače), délku trvání v sekundách a nanosekundách a především samotnou amplitudu síly vibrace.
Vzhledem k úspornému principu zpracování na koncovém mikrokontroleru je tato složitá zpráva na proxy serveru přepočítána a sloučena do jednoduchého sedmiznakového řetězce (např. R255100), jenž přímo reprezentuje zpracovanou stranu, střídu PWM v rozsahu 0–255 a dobu trvání v milisekundách v rozsahu 0–999. Celý tento proces datové transformace ilustruje tabulka 4.

tabulka 4: Proces zpracování haptické zprávy z ALVR

Originální data z WebSocket (JSON) | Interpretace a mapování proxy serverem
"path": "/user/hand/right/..." "amplitude": 1.0 "duration": {"secs": 0, "nanos": 100000000} | Indikuje pravou ruku → počá-teční znak R Vynásobeno 255 → střída mo-toru 255 (až 3 pozice) Převod na milisekundy → čas 100 (až 3 pozice)
Výsledný vygenerovaný povel | R255100

Finální převedený příkaz je odeslán jako všesměrový UDP paket na port 8888.

1 | def on_message ( ws , message ) :
2 | data = json . loads ( message )
3 | event = data . get (" event_type ", {}) . get (" data ", {})
4 | path | = event . get (" path ", "")
5 | duration | = event . get (" duration ", {})
6 | amplitude = event . get (" amplitude ")

7
8 | ctrl = None
9 | if "/ user / hand / right " in path : ctrl = "R"
10 | elif "/ user / hand / left " in path : ctrl = "L"

11
12 | if ctrl and duration and amplitude is not None :
13 | dur_ms = ( duration . get (" secs ", 0) * 1000
14 | | + duration . get (" nanos ", 0) / 1 e6 )
15 | duty | = max (0 , min (255 , int( amplitude * 255) ) )
16 | dur_ms = max (0 , min (999 , dur_ms ) )
17 | send_to_esp32 ( ctrl , duty , dur_ms )

ukázka kódu 4: Zpracování haptické zprávy ze WebSocket

## 6.6 Ukončení relace

Proxy server naslouchá přerušení KeyboardInterrupt (Ctrl+C). Po jeho zachycení jsou signály "STOP" odesílány dvojicí paralelních kanálů: jednak jako všesměrové zprávy na adresu 255.255.255.255, jednak jako jednosměrné datagramy přímo na konkrétní IP adresy připojených ovladačů. Tento dvouvrstvový přístup je záměrnou pojistkou. Plošné odeslání pokryje případ, kdy je IP adresa ovladače neznámá, zatímco jednosměrné datagramy eliminují riziko, že by síťový směrovač (router) všesměrové pakety odfiltroval nebo omezil.

# 7 Integrace se softwarem ALVR a platformou SteamVR

ALVR (Air Light VR) je otevřený software, jenž zprostředkovává bezdrátový přenos VR obrazového toku z osobního počítače do mobilní náhlavní soupravy.[1] Kromě samotného přenosu obrazu disponuje ALVR veřejným aplikačním rozhraním (REST API a WebSocket), jež projektu NeoGrip umožňuje vkládat vlastní vstupy ovladačů přímo do virtuálního prostředí SteamVR.

## 7.1 Úloha ALVR v architektuře projektu

Z pohledu systémové architektury NeoGripu plní ALVR dvojí roli. Na straně vstupu přijímá přes REST API data o stisknutých tlačítkách a pohybu páčky a předává je jako standardní vstupy virtuálního ovladače do SteamVR. Na straně výstupu naopak generuje prostřednictvím WebSocket události haptické odezvy, které proxy server přeposílá na fyzický ovladač ESP32.
ALVR tak tvoří klíčovou integrační vrstvu, bez níž by přímá komunikace vlastního firmwaru se SteamVR nebyla realizovatelná bez vývoje vlastního specializovaného ovladače.
Důležitým a kritickým momentem samotného vývoje projektu se proto stala skutečnost, že tato programová komunikační struktura a příslušné dokumentace (API) softwaru ALVR v době tvorby projektu nebyla, a ve své podstatě aktuálně stále ještě není, zcela veřejně dostupná, sjednocená ani plně zmapovaná. Jelikož API nebylo plně zdokumentováno, bylo nutné během vývoje navázat přímý kontakt s vývojáři softwaru ALVR a spolupracovat na experimentálním mapování vstupních cest, dekódování portů a luštění správných vnitřních těles ve formátu JSON.

## 7.2 Prostorové sledování pomocí optického snímání rukou

Vzhledem k tomu, že samotné fyzické moduly ovladače NeoGrip neobsahují vlastní poziční senzory ani infračervené diody pro prostorové sledování, projekt využívá zabudovanou funkci optického sledování orientace a pozice rukou[7] v náhlavní soupravě Meta Quest. V nastavení softwaru ALVR se díky speciální konfiguraci vytvoří profil „virtuálních ovladačů“, kterým jsou v reálném čase automaticky plynule přiřazována orientační a poziční data s šesti stupni volnosti (6DoF) generovaná vestavěnými kamerami z náhlavní soupravy. Aby proces rozpoznávání přirozených pohybů rukou nenarušoval samotné hraní v důsledku falešných odezev, jsou softwarová gesta napodobující stisky v konfiguraci účelově vypnuta. Proxy server projektu NeoGrip následně prostřednictvím aplikačního rozhraní pouze „vkládá“ přesná data o stisknutých fyzických tlačítkách a výchylkách páčky z ESP32 do těchto předpřipravených virtuálních ovladačů se známou prostorovou polohou. Výsledkem je plnohodnotné spojení optického prostorového sledování a přesných mechanických hmatových vstupů.

## 7.3 Formát vstupních dat

Aplikační rozhraní ALVR přijímá seznam objektů JSON, kde každý objekt reprezentuje jeden vstup. Každý objekt obsahuje dva klíče: path specifikuje konkrétní vstup dle standardu OpenXR a value nese jeho hodnotu. Hodnota může být skalární veličina (Scalar) pro analogové vstupy nebo logická hodnota (Binary) pro digitální tlačítka. Přehled nejdůležitějších vstupních cest pro levý ovladač je v tabulce 5.

tabulka 5: Vstupní cesty ALVR API (levý ovladač)

Cesta | Typ hodnoty | Popis vstupu
.../trigger/value .../squeeze/value .../x/click .../y/click .../system/click .../thumbstick/x .../thumbstick/y .../thumbstick/click | Scalar Scalar Binary Binary Binary Scalar Scalar Binary | Analogová spoušť (0,0–1,0) Úchopový senzor (0,0–1,0) Tlačítko X Tlačítko Y Systémové tlačítko Vodorovná osa páčky Svislá osa páčky Stisk páčky

## 7.4 Konfigurace ALVR

Před prvním spuštěním je nutné ALVR správně nakonfigurovat, aby akceptoval vstupy z proxy serveru NeoGrip namísto vstupů z originálních ovladačů.
Zásadní je vypnout v nastavení ALVR v záložce Presets možnost Hand tracking interaction, protože nechceme používat gesta rukou, ale náš ovladač pro interakci.
Dále musí být v záložce Headset zapnuty položky Controllers, Tracked, Multimodal tracking a Haptics. Je nutné se ujistit, že SteamVR Input 2.0 je vypnutý a Hand tracking interaction také.
Postup nastavení je zdokumentován na následujících snímcích obrazovky (viz obrázky 9–11).

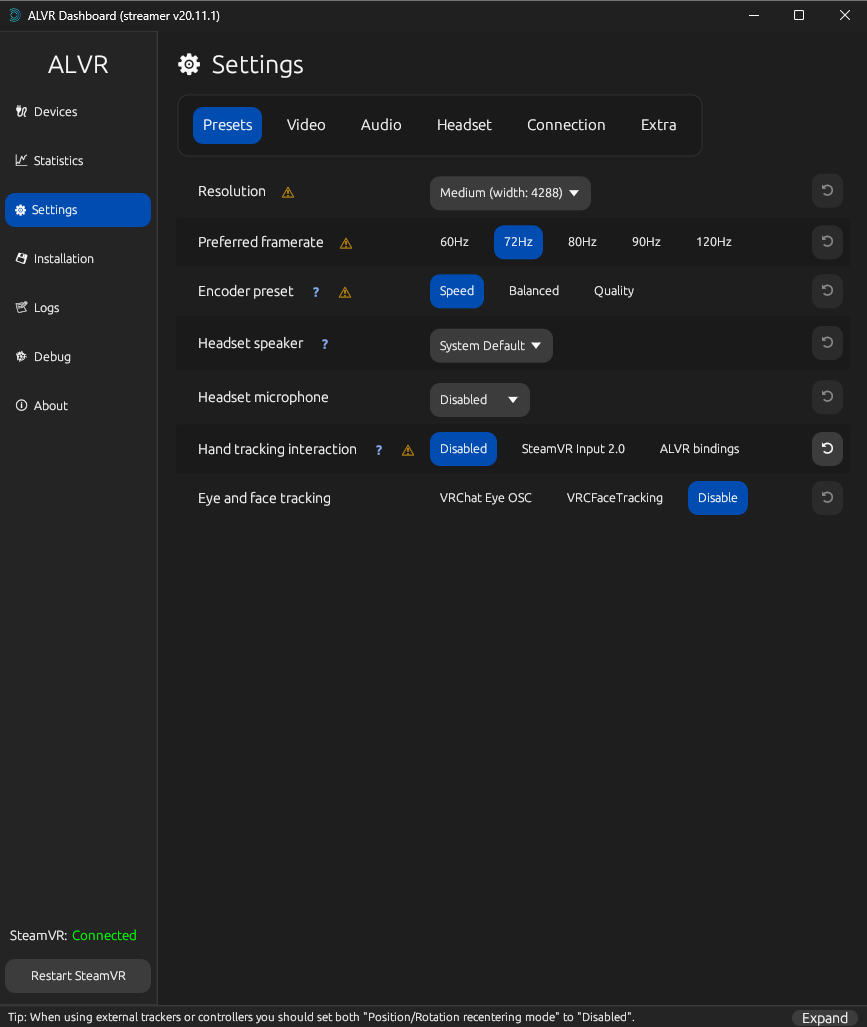
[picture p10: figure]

obrázek 9: Krok 1: Nastavení v záložce Presets

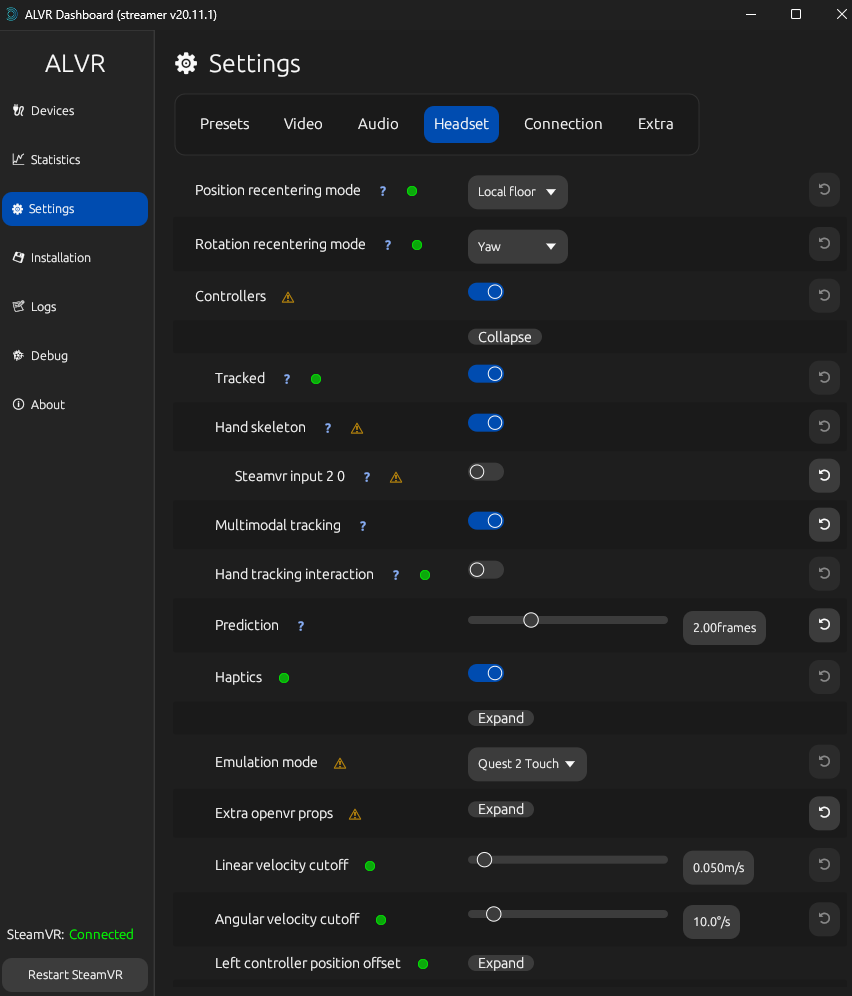
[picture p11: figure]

obrázek 10: Krok 2: Nastavení v záložce Headset

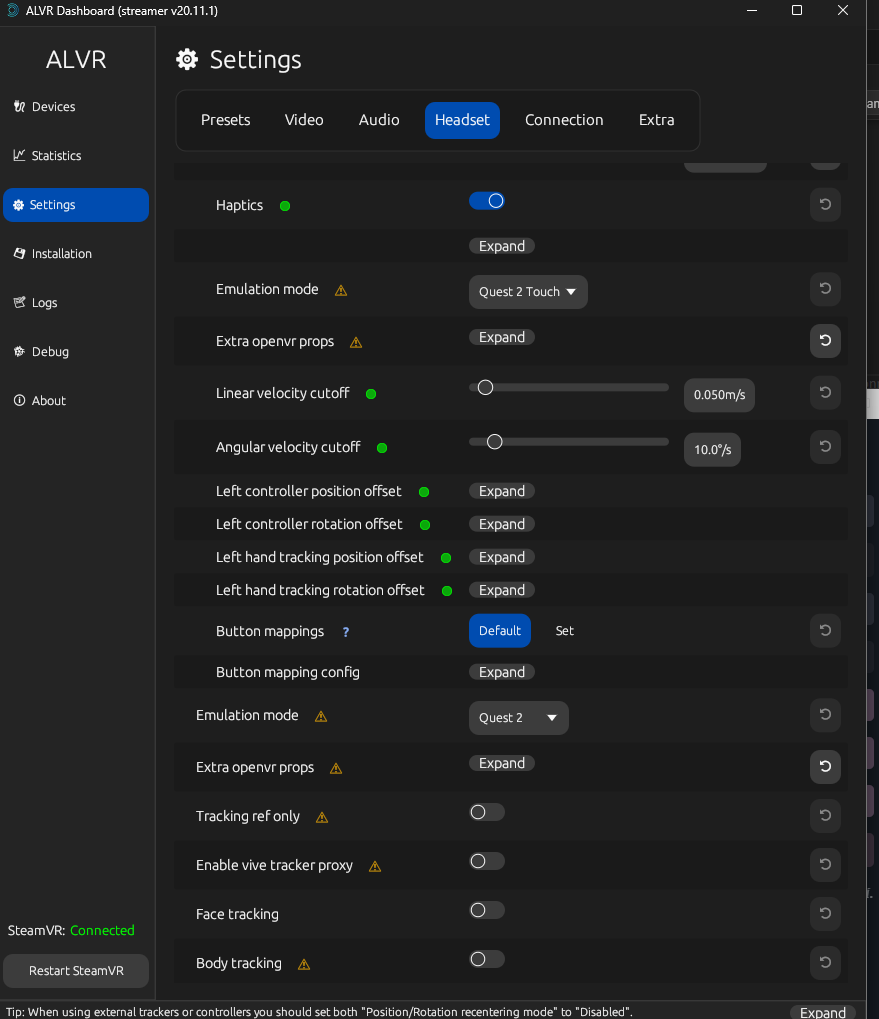
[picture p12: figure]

obrázek 11: Krok 3: Dodatečné konfigurace

# 8 Instalace a spuštění

Tato kapitola popisuje kompletní postup přípravy prostředí a prvního spuštění systému NeoGrip. Postup předpokládá, že uživatel má k dispozici sestavený fyzický ovladač a počítač s operačním systémem Windows 10 nebo novějším.

## 8.1 Požadavky na software

Před spuštěním je nutné připravit následující softwarové závislosti:

- Firmware ovladače — zkompilovaný a úspěšně nahraný zdrojový kód do mikrokontroleru ESP32.
- NeoGrip proxy server — spouštěcí skript v jazyce Python (NeoGrip.py), který běží na počítači uživatele — dostupný na adrese https://github.com/AthemiS13/NeoGrip/blob/main/VR-Firmware/NeoGrip-Proxy/NeoGrip.py. (https://github.com/AthemiS13/NeoGrip/blob/main/VR-Firmware/NeoGrip-Proxy/NeoGrip.py)
- SteamVR — dostupný zdarma prostřednictvím platformy Steam.[5]
- ALVR — dostupný na adrese https://github.com/alvr-org/ALVR. Doporučuje se verze V20.11.1 [1]
- Python (verze 3.10 a novější) — dostupný na https://www.python.org/.[6]
- Závislosti proxy serveru — instalovatelné příkazem:

1 pip install requests websocket - client

ukázka kódu 5: Instalace závislostí proxy serveru příkazem pip

## 8.2 Příprava ovladačů

Pro správnou funkci je zapotřebí vybavit mikrokontroler příslušným vnitřním programem (firmwarem). Před jeho implementací do čipu je nutné nastavit základní parametry lokální bezdrátové sítě, tedy název sítě (SSID) a příslušné heslo, prostřednictvím kterých bude ovladač komunikovat. Rovněž je nezbytnou součástí konfigurace správné určení identifikátoru strany "L" pro levý a "R" pro pravý ovladač. Samotné nahrávání zkompilovaného zdrojového kódu probíhá ve snadno přístupném programu Visual Studio Code za doprovodu rozšíření a vývojového prostředí PlatformIO. Osoba, která chce nahrát projekt NeoGrip, jednoduše napřímo připojí desku ESP32 pomocí libovolného synchronizačního datového kabelu k USB portu osobního stolního počítače (předem nezáleží, zda disponuje standardem rozhraní Micro-USB nebo modernějším USB-C). Díky připravenému tlačítku „Upload“ z nabídky PlatformIO již editor sám automaticky projde postupem sestavení jazyka C++ a binární data spolehlivě zapíše do paměti připojeného čipu.
S tímto krokem je hotový software zaveden a hardware plně připraven k provozu.

## 8.3 Postup spuštění relace

Kompletní spuštění NeoGripu probíhá v následujícím pořadí kroků:

1. Spustit SteamVR a ALVR. V nastavení ALVR ověřit konfiguraci dle postupu popsaného v kapitole 7.
2. Spustit proxy server příkazem python NeoGrip.py. Terminál zobrazí hlášení o zahájení vysílání signálu "START".
3. Stisknout systémové tlačítko fyzického ovladače, čímž se zařízení probudí z hlubokého spánku, připojí se k síti Wi-Fi a obdrží signál "START". Potvrzení úspěšného připojení proběhne krátkým vibračním impulsem.
4. Ovladač je nyní připraven k provozu. Veškeré vstupy jsou v reálném čase předávány do prostředí SteamVR.
5. Pro ukončení relace stačí v terminálním okně stisknout Ctrl+C. Proxy server odešle signál "STOP" a ovladač přejde do hlubokého spánku.

# 9 Testování a výsledky

V této kapitole jsou detailně popsány procedury a výsledky testování ovladačů NeoGrip. Aby bylo možné objektivně posoudit použitelnost navrženého řešení v praxi, byl systém podroben komplexní sadě testů. Testování se primárně zaměřilo na pět klíčových vlastností nezbytných pro plynulý prožitek z virtuální reality: spolehlivost komunikace, celkovou latenci systému, věrnost a chování haptické odezvy, energetickou nezávislost (výdrž baterie) a konečně preciznost aktivace správných tlačítek a vstupů.

## 9.1 Spolehlivost komunikace

Prvním a zcela zásadním testovaným aspektem byla spolehlivost bezdrátového přenosu dat. Ovladače a proxy server spolu komunikují prostřednictvím rychlého protokolu UDP v pásmu 2.4 GHz (Wi-Fi). Vzhledem k absenci potvrzovacích mechanismů bylo nutné ověřit, nakolik je tento tok stabilní v běžném zarušeném prostředí domácí sítě.
Pro testování byl využit nástroj pro analýzu síťového provozu (Wireshark)[15], pomocí něhož byly sledovány odchozí pakety z mikrokontroleru ESP32 a příchozí data na proxy serveru na osobním počítači. Měření probíhalo po dobu několika hodin souvislého provozu, přičemž vzdálenost mezi ovladači a Wi-Fi směrovačem se pohybovala od jednoho do pěti metrů.
Výsledky: Analýza ukázala, že četnost ztracených paketů (packet loss) v lokální bezdrátové síti je při přímé viditelnosti směrovače prakticky zanedbatelná, na úrovni hluboko pod jedním procentem. Firmware ESP32 konzistentně odesílá patnáctiznakové stavové pakety přesně každých 40 ms (tj. 25 paketů za sekundu pro každý ovladač). Pokud i došlo ke ztrátě ojedinělého UDP datagramu, kvůli vysoké frekvenci obnovování (25 Hz) byl tento výpadek okamžitě překryt přijetím následujícího paketu a na straně uživatele se tak neprojevil žádným znatelným zásekem či vynecháním pohybu ve virtuálním světě. Bezdrátové připojení lze tedy pro tyto účely označit za vysoce spolehlivé.

## 9.2 Latence

S komunikací úzce souvisí latence celého řetězce, která je u zařízení pro virtuální realitu kritickým parametrem. Vysoká latence (zpoždění) mezi fyzickým stiskem tlačítka a jeho následným promítnutím do VR by nevyhnutelně vedla k uživatelskému diskomfortu, snížené interaktivitě a potenciálně i k nevolnosti (tzv. kinetóze).
Celková doba odezvy v architektuře projektu NeoGrip je součtem několika dílčích zpoždění: snímání hardwaru mikrokontrolerem (maximálně 40 ms), samotný Wi-Fi přenos po lokální síti (typicky 1–3 ms), zpracování proxy serverem v rámci programu v jazyce Python (méně než 1 ms) a konečné překlopení přes REST API projektu ALVR do systému SteamVR.
Výsledky: Přestože probíhá na pozadí komplikovaný překlad a směrování signálů na několika vrstvách, praktické testování neprokázalo žádné rušivé zpoždění. Reakce na stisknutí či vychýlení páčky se ve virtuálním prostředí projevují okamžitě (v rámci překreslovací frekvence náhlavní soupravy). Celková změřená latence „od stisku k akci“ se průměrně pohybuje pod hranicí 50 ms, což pro účely ovládání běžných interakcí bezpečně postačuje a nečiní problém ani při rychlejších herních titulech.

## 9.3 Haptická odezva

Haptická zpětná vazba dodává virtuálnímu světu materiální iluzi. Při testování byla zkoumána správná reakce vibračních motorků na pulzy generované hrou (např. při střelbě, zvednutí předmětu či interakci s virtuálním menu). Změny amplitudy a délky trvání signálu jsou ze SteamVR exportovány skrze ALVR WebSocket do proxy serveru, který je redukuje na pulzně-šířkovou modulaci (PWM) pro koncový čip ESP32.
Výsledky: Zapojení motorků přes PNP tranzistory a softwarový PWM překlad se v praxi osvědčily jako výborné řešení. Přesnost časování vibrací je výborná a haptika se nezkracuje ani neprodlužuje. Taktéž variabilní intenzita odpovídá síle haptické ukázky ze SteamVR. Během testů bylo navíc ověřeno, že provoz motorku (a tím pádem zvýšený odběr proudu z napájecí kaskády) nijak nedegraduje signál analogových páček odečítaný přes převodníky ADC1, ani nevede k výpadkům či restartům mikrokontroleru.

## 9.4 Výdrž na jedno nabití a doba nabíjení

Z hlediska uživatelské přívětivosti nesmí ovladač trpět nutností častého připojování ke zdroji napájení. NeoGrip využívá integrovaný lithio-polymerový (Li-Po) akumulátor s kapacitou 500 mA h s jmenovitým napětím 3.7 V.
Spotřeba ovladače se skládá z napájení výpočetního jádra ESP32, kontinuálního chodu integrovaného Wi-Fi vysílače a nárazového odběru haptického motorku. Při dlouhodobém testu nepřetržité VR relace bylo dosaženo provozní doby přibližně 6 hodin aktivního používání. Tato doba spolehlivě pokrývá i neobvykle dlouhé intervaly ve virtuální realitě.
Třetím testovaným parametrem energetické nezávislosti je doba samotného nabíjení. V ovladači se o bezpečnou distribuci nabíjecího proudu z konektoru USB stará nabíjecí modul s čipem TP4056. Tento standardní obvod se z výroby běžně osazuje programovacím rezistorem s odporem 1.2 kΩ, což podle katalogového listu nastavuje maximální hodnotu nabíjecího proudu na 1000 mA (1 A). Tento proud ovšem představuje pro použitou 500 mA h baterii nabíjení na hranici doporučených specifikací (nabíjecí proud 2C). Pro ideální sériovou výrobu by proto bylo vhodné vyměnit rezistor Rprog na modulu za hodnotu přibližně 2.4 kΩ, čímž by se maximální nabíjecí proud snížil na bezpečnějších 500 mA (1C).
Teoretický výpočet doby plného nabití akumulátoru s kapacitou 500 mA h (neboli 0.5 A h) by při ideálním přísunu stejnosměrného proudu 1 A vypadal následovně:

t =

C
I

=

500 mA h
1000 mA = 0,5 h = 30 min | (2)

Proces nabíjení lithiových článků ovšem není po celou dobu lineární. Obvod TP4056 automaticky využívá dvoufázovou metodu CC/CV (Constant Current / Constant Voltage). Na začátku cyklu se článek plní konstantním proudem 1 A. Jakmile jeho napětí dosáhne hraniční hodnoty 4.2 V, přechází modul do fáze konstantního napětí a nabíjecí proud pozvolna asymptoticky klesá téměř k nule. Z tohoto důvodu trvá reálné nabití ovladače z úplného vybití do 100 % kapacity (signalizováno zhasnutím červené a rozsvícením modré stavové LED diody na modulu) přibližně 45 minut, což je velmi přijatelná doba.

## 9.5 Aktivace správných tlačítek a vstupů na virtuálním ovladači

Klíčovým posláním celého spletitého softwarového převodu je bezchybné zrcadlení hardwarových stisků do modelů virtuálních rukou. Kompatibilita byla ověřována přímou kontrolou v diagnostickém překryvu vstupů ve SteamVR i praktickým testováním v několika rozšířených typech herních aplikací.
Výsledky: Korektní interpretace vstupů byla zcela naplněna a zmapování všech fyzických tlačítek proběhlo úspěšně:
- Akční tlačítka (A/X, B/Y): hlásí stisk v binární hodnotě bez zaváhání.
- Systémové tlačítko: spolehlivě vyvolává hlavní panel platformy SteamVR, případně při delším podržení resetuje středový pohled uživatele.
- Spoušť a boční úchop (Grip): jsou na rozdíl od originálních ovladačů řešeny mechanickými koncovými spínači bez možnosti analogového tlaku. Softwarový převod však elegantně při stisku přiřazuje mezní hodnotu 1,0 (plné stisknutí), což ke standardní interakci uvnitř velkého množství her a ke zvedání předmětů bohatě dostačuje.
- Analogové páčky a jejich klik (Joy click): snímají napětí z potenciometrů. Osa X a Y po normalizaci úspěšně odesílá do aplikačního rozhraní desetinné údaje v rozsahu intervalu ⟨−1,0; 1,0⟩. Drobné odchylky a přirozené chvění (drift)⁴ použitých fyzických modulů KY-023 bylo úspěšně vyřešeno softwarovým nastavením „mrtvé zóny“ v ovládacím centru SteamVR. V centrální zóně od −0,1 do +0,1 jsou vstupy ignorovány, čímž se plně kompenzují nedokonalosti součástky.

Lze konstatovat, že systém NeoGrip úspěšně transformuje všechny potřebné fyzické vjemy do virtuálního OpenXR standardu s vysokou přesností a garantovanou funkčností. Testování navíc potvrdilo spolehlivou součinnost obou ovladačů (pravého a levého) připojovaných do proxy serveru souběžně bez vzájemného křížení zpráv. Co se týče samotného optického sledování rukou pomoci kamer z náhlavní soupravy (čímž se nahrazuje chybějící vlastní hardwarové sledování na ovladači), je nutné zmínit, že pro svou adekvátní funkčnost je přímo závislé na ideálních světelných podmínkách.

4Samovolná odchylka (drift) páčky označuje jev, kdy páčka v klidové poloze neodesílá přesně střední hodnotu, ale mírně vychýlenou, což způsobuje nechtěný pohyb ve virtuálním prostředí.

# 10 Závěr

Projekt NeoGrip demonstroval, že je možné vytvořit plně funkční a cenově dostupné ovladače pro virtuální realitu na bázi snadno dostupných komponent, zejména mikrokontroleru ESP32 a propojit je s platformou SteamVR prostřednictvím otevřeného softwaru ALVR a vlastního proxy serveru napsaného v jazyce Python.
Stěžejním výsledkem práce je právě tato softwarová vrstva, která v reálném čase přijímá, dekóduje a překládá hardwarové vstupní signály do standardizovaného komunikačního formátu REST API. Vrstva je navržena jako vícevláknová aplikace zajišťující souběžné zpracování příchozích dat, odesílání na ALVR a příjem haptické zpětné vazby bez vzájemného blokování procesů.
Hardwarová část projektu prokázala, že 3D tisk ve spojení s dostupnými elektronickými moduly umožňuje sestrojit ovladač s ergonomikou srovnatelnou s komerčními produkty, přičemž celkové náklady na výrobu jednoho páru zůstávají výrazně pod cenou originálního příslušenství.
Systém byl úspěšně otestován v prostředí SteamVR s náhlavní soupravou Meta Quest 2 a dosáhl plné funkčnosti ve všech klíčových oblastech: registrace tlačítek, analogový pohyb páčky, haptická zpětná vazba a správa napájení. Veškerý zdrojový kód a výkresová dokumentace jsou volně a zdarma dostupné.
Do budoucna by bylo zajímavé rozšířit projekt například o přidání bateriového indikátoru prostřednictvím ADC měření aktuálního napětí Li-Po článku, případně systémově vyladit softwarovou kompenzaci odchylky (driftu) osy páčky algoritmicky rovnou na úrovni firmwaru čipu ESP32. Významným vylepšením by z uživatelského hlediska byla implementace funkce Wi-Fi Manager, která by nahradila současné pevné nastavení sítě ve zdrojovém kódu (hardcoding). Po prvním spuštění by mikrokontroler vytvořil vlastní přístupový bod (AP) a umožnil uživateli zadat heslo k lokální síti pohodlně přes webový prohlížeč v mobilním telefonu. I přes drobná úskalí a omezení kladená na samotné optické sledování rukou, které přirozeně není dokonalé a vyžaduje dobrou viditelnost pro kamery, představuje NeoGrip velmi elegantní, mimořádně cenově výhodnou a vysoce funkční alternativu k původnímu komerčnímu příslušenství.

# Bibliografie

[1] ALVR Contributors. ALVR — Air Light VR [online]. 2024. Dostupné z: https: //github.com/alvr-org/ALVR [cit. 2026-03-20].
[2] Espressif Systems. ESP32 Series Datasheet [online]. Version 4.7. Espressif, 2024. Dostupné z: https://www.espressif.com/sites/default/files/documentation/esp32_datasheet_en.pdf (https://www.espressif.com/sites/default/files/documentation/esp32_datasheet_en.pdf) [cit. 2026-03-20].
[3] Cloudflare. What is UDP? | User Datagram Protocol [online]. Dostupné z: https://
www.cloudflare.com/learning/ddos/glossary/user-datagram-protocol-udp/ [cit. 2026-04-01].
[4] Khronos Group. OpenXR Specification [online]. Version 1.1. 2024. Dostupné z: https://registry.khronos.org/OpenXR/specs/1.1/html/xrspec.html [cit. 2026-03-20].
[5] Valve Corporation. SteamVR [online]. 2024. Dostupné z: https://store.steampowered.com/app/250820/SteamVR/ (https://store.steampowered.com/app/250820/SteamVR/) [cit. 2026-04-01].
[6] Python Software Foundation. Python Documentation [online]. Verze 3.12. 2024. Dostupné z: https://docs.python.org/3/ [cit. 2026-03-20].
[7] Meta. Hand Tracking in Meta Quest [online]. 2024. Dostupné z: https://developer.oculus.com/documentation/unity/unity-handtracking/ (https://developer.oculus.com/documentation/unity/unity-handtracking/) [cit. 2026-04-01].
[8] Chmelař, J. NeoGrip — open-source VR ovladač [online]. GitHub, 2024. Dostupné z: https://github.com/AthemiS13/NeoGrip [cit. 2026-03-20].
[9] Python Software Foundation. threading — Thread-based parallelism [online]. Dostupné z: https://docs.python.org/3/library/threading.html [cit. 2026-03-26].
[10] PlatformIO Labs. PlatformIO: An open-source ecosystem for IoT development [online]. Dostupné z: https://platformio.org/ [cit. 2026-03-26].
[11] Kurose, J. F. a Ross, K. W. Computer Networking: A Top-Down Approach. 8. vyd. Pearson, 2021. ISBN 978-0136681557.
[12] Prusa Research. Materiál PLA [online]. Dostupné z: https://help.prusa3d.com/cs/article/pla_2062 (https://help.prusa3d.com/cs/article/pla_2062) [cit. 2026-03-26].
[13] zmerp (vývojář ALVR). Osobní konzultace ohledně ochranné politiky CSRF v aplikačním rozhraní ALVR. [online komunikace]. 2025.
[14] SparkFun Electronics. Pulse Width Modulation [online]. Dostupné z: https://learn.sparkfun.com/tutorials/pulse-width-modulation/all [cit. 2026-04-01].
[15] Wireshark Foundation. Wireshark [online]. Dostupné z: https://www.wireshark.org/ (https://www.wireshark.org/) [cit. 2026-04-01].

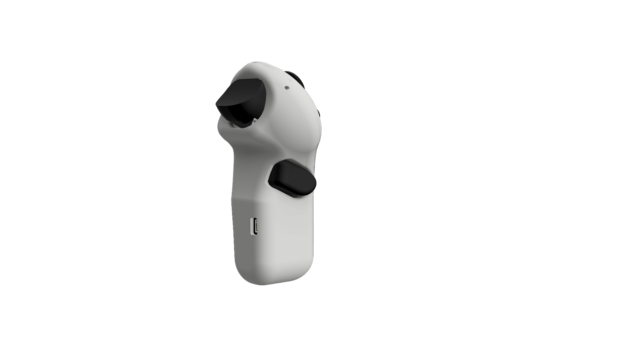
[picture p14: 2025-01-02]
Assets/v2back.png

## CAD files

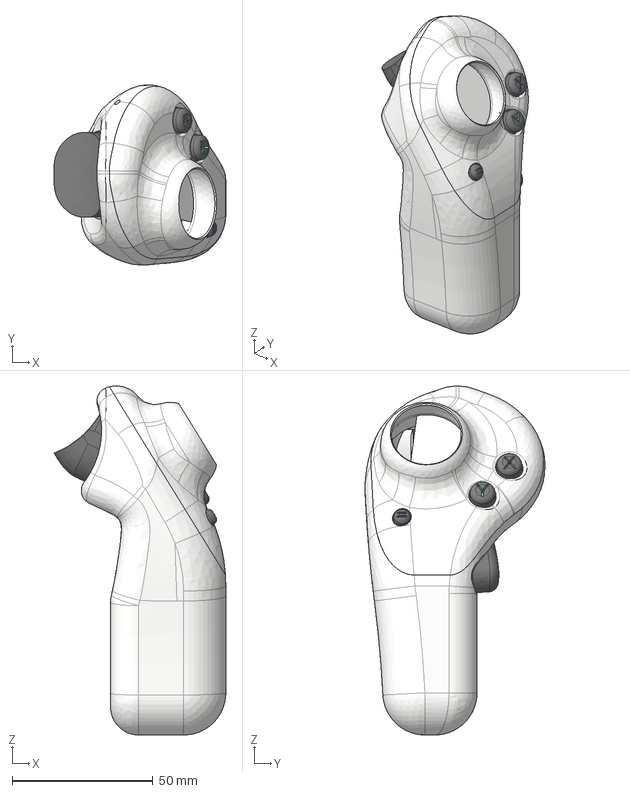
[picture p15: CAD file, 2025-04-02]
STEP-Files/NeoGrip-L.step
61.0 x 64.0 x 124.0 mm
rod(Mirror)
truig(Mirror)
grab(Mirror)
grabrod(Mirror)
x v1(Mirror)
y v1(Mirror)
menu v1(Mirror)
maain(Mirror)
maintop(Mirror)
buttonhoder(Mirror)
coverholder(Mirror)
switchholder(Mirror)

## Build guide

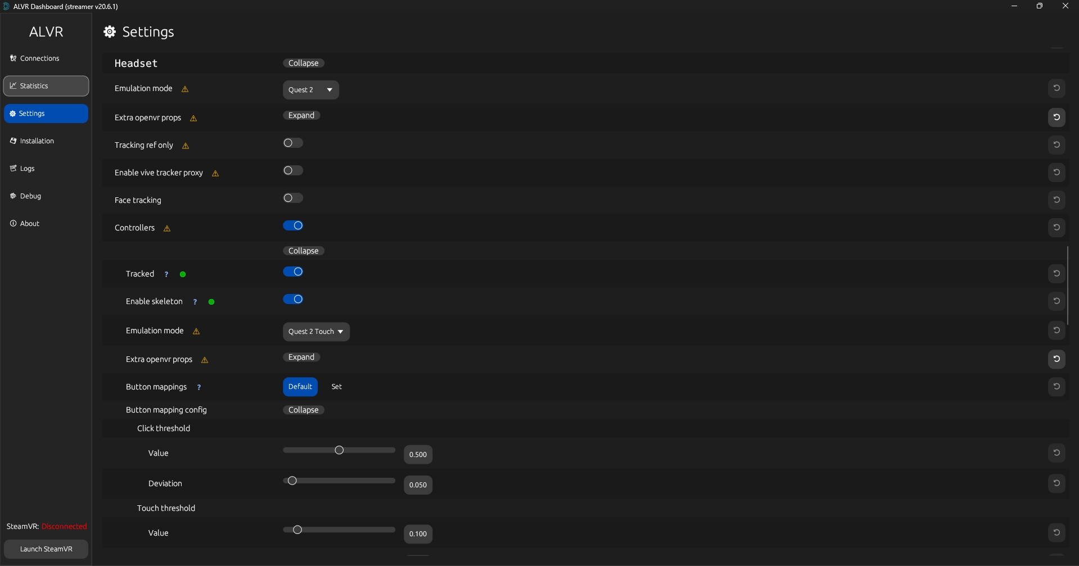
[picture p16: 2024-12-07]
Config/ALVR/ALVRSETUP1.png

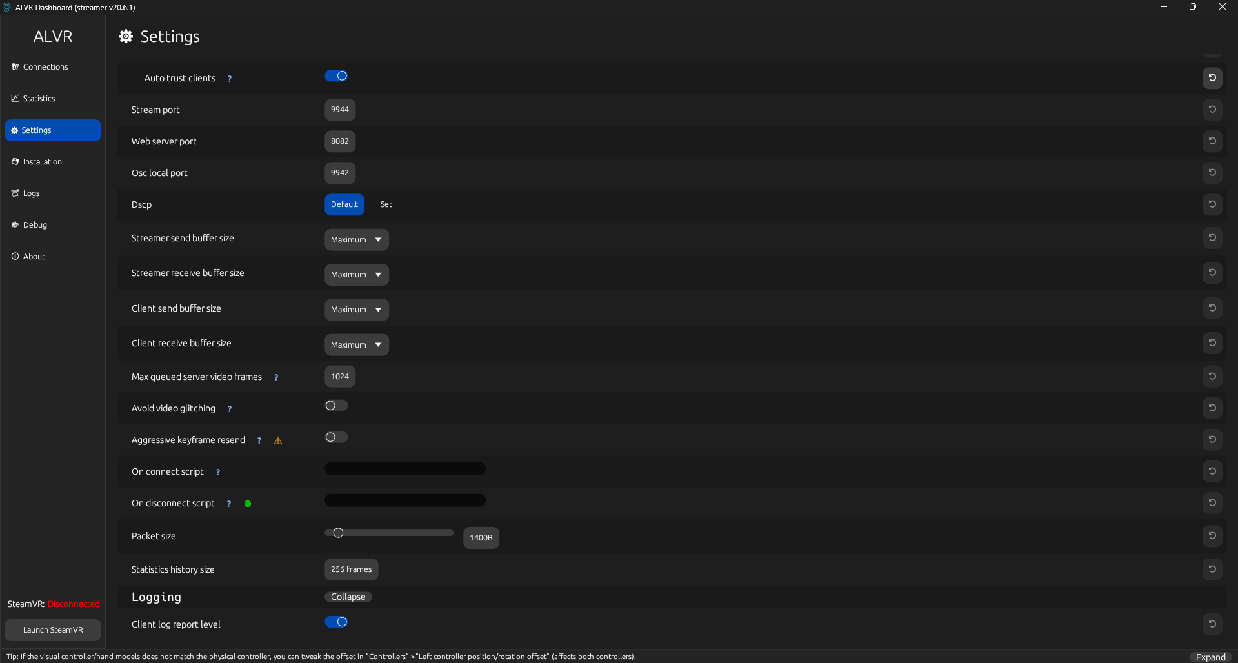
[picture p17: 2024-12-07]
Config/ALVR/ALVRSETUP3.png

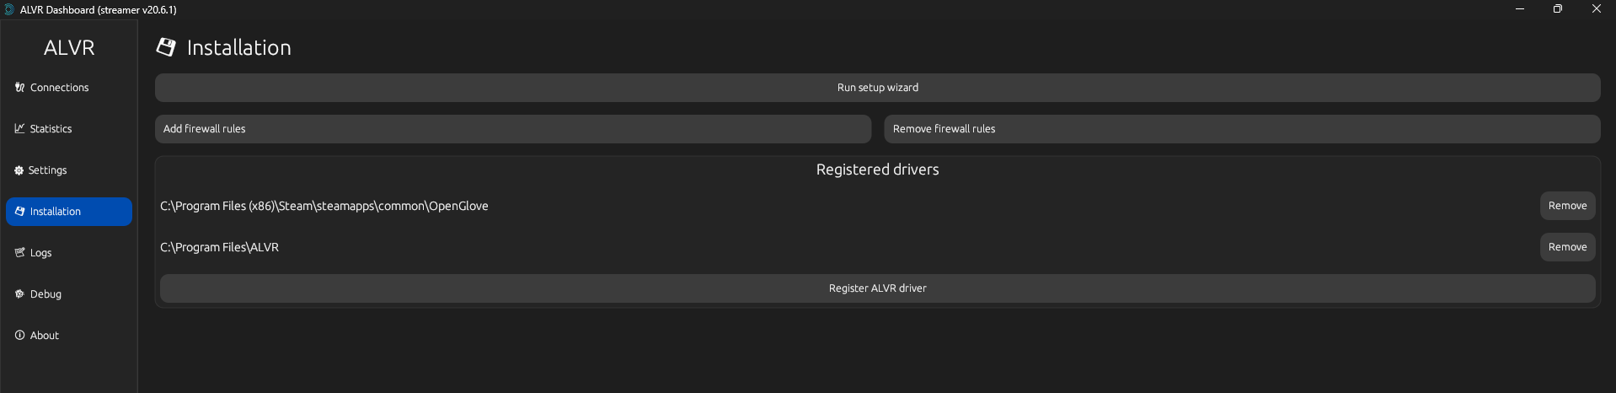
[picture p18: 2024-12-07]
Config/ALVR/ALVRSETUP5.png

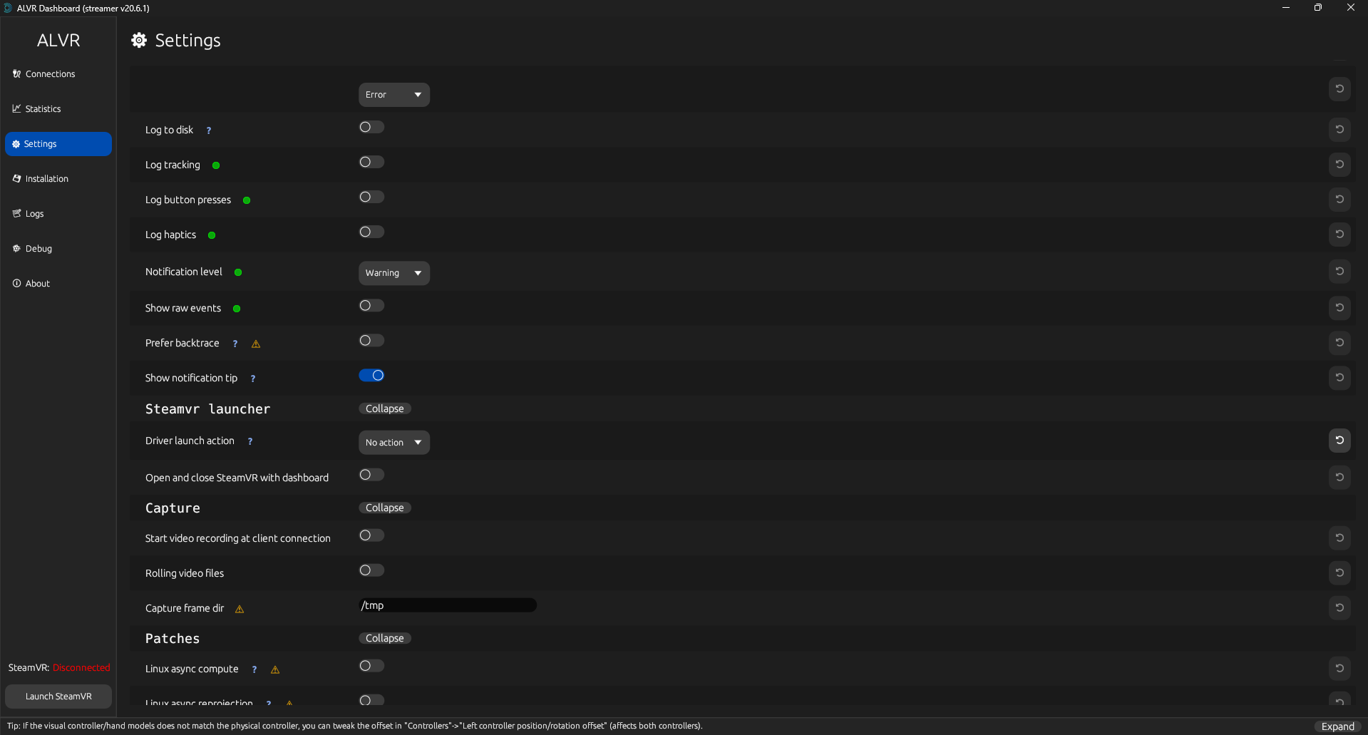
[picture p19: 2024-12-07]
Config/ALVR/ALVRSETUP4.png

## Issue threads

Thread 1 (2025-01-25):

Clarifying if this can be used to replace controllers for factory-defaulted setup in Q2?

loosebinding, 2025-01-25:
I bought a Q2 without one of the controllers, and thought I could DIY my own.  Ha!

But it looks like that is what this is!  Can you help me to understand if I could use this to get past the initial setup screen?

AthemiS13, 2025-01-25:
Hello,No, this wont help you get past the setup. It allows you to control steam vr games if you dont own controllers. But you can bypass the initial screen by buying original meta controllers from your local shop and than returning them after you get past the screen and turn on the hand tracking. It has a few downsides… You cant factory reset the device, otherwise you would have to do it all over again. And I dont know the shopping policy in your country. In europe, it is completely legal to buy a product and than return it instantly with no questions asked. Hopefully now you understand better,Jakub ChmelařOn Jan 25, 2025, at 11:38 PM, loosebinding ***@***.***> wrote:
I bought a Q2 without one of the controllers, and thought I could DIY my own.  Ha!
But it looks like that is what this is!  Can you help me to understand if I could use this to get past the initial setup screen?

—Reply to this email directly, view it on GitHub, or unsubscribe.You are receiving this because you are subscribed to this thread.Message ID: ***@***.***>

Closed 2025-01-29.

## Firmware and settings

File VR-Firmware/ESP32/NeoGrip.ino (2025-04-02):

#include <Arduino.h>
#include <WiFi.h>
#include <WiFiUdp.h>
#include "esp_sleep.h"

// WiFi credentials
const char* ssid = ""; // Your WiFi SSID
const char* password = ""; // Your WiFi password

// UDP settings
WiFiUDP udp;
const unsigned int localPort = 9999;   // Port where ESP32 sends packets
const unsigned int hapticPort = 8888;  // Port to receive haptic data
const unsigned long sendInterval = 40; // 40ms interval for sending data

unsigned long previousMillis = 0;
char incomingPacket[255];  // Buffer to store incoming packets

const char *controllerType = "R";  // 'L' for left controller, 'R' for right controller

// GPIO Pins for buttons RIGHT
const int buttonA = 21;
const int buttonB = 18;
const int buttonSYS = 4;  // Also used as wakeup button
const int buttonJOYCLK = 14;
const int buttonTRIG = 19;
const int buttonSQZ = 27;
const int joyXPin = 34;
const int joyYPin = 35;

// PWM settings for haptic feedback
const int motorPin = 16;
const int pwmResolution = 8;
const int fixedFrequency = 200;
const int maxDuty = 255; // Full Speed
const int minDuty = 0; // OFF

// Timing control for haptic motor without delay
unsigned long motorEndTime = 0;

// Flags to track START/STOP detection
bool receivedStart = false;

void goToDeepSleep() {
    Serial.println("[SYSTEM] Going to deep sleep...");

    // Configure wake-up source (GPIO 4 - buttonSYS)
    esp_sleep_enable_ext0_wakeup((gpio_num_t)buttonSYS, LOW);
    hapticSignal();

    // Enter deep sleep
    esp_deep_sleep_start();

}

void waitForStart() {
    Serial.println("[WAIT] Waiting for START signal...");

    unsigned long startTime = millis();  // Record wake-up time
    const unsigned long timeout = 60000; // 60 seconds timeout

    while (!receivedStart) {
        int packetSize = udp.parsePacket();
        if (packetSize) {
            int len = udp.read(incomingPacket, sizeof(incomingPacket) - 1);
            if (len > 0) {
                incomingPacket[len] = '\0';
            }
            Serial.printf("[UDP] Received: %s\n", incomingPacket);

            if (strcmp(incomingPacket, "START") == 0) {
                receivedStart = true;
                Serial.println("[SYSTEM] START received! Proceeding...");
                hapticSignal();
                return;  // Exit function and continue normal operation
            }
        }

        // Check if 30 seconds have passed
        if (millis() - startTime >= timeout) {
            Serial.println("[TIMEOUT] No START received. Going back to deep sleep...");
            goToDeepSleep();
        }

        delay(50);  // Small delay to prevent busy-waiting
    }
}

void setup() {
    Serial.begin(115200); 

    // Connect to WiFi
    WiFi.begin(ssid, password);
    unsigned long startAttemptTime = millis();
    while (WiFi.status() != WL_CONNECTED) {
        Serial.print(".");
        delay(500);

                // Restart ESP if it fails to connect within 10 seconds
        if (millis() - startAttemptTime >= 10000) {
            Serial.println("\n[ERROR] Failed to connect to WiFi! Restarting ESP...");
            ESP.restart();
        }
    }
    Serial.println("\n[SYSTEM] Connected to WiFi!");
    Serial.print("IP Address: ");
    Serial.println(WiFi.localIP());
    // Start UDP listening
    udp.begin(localPort);
    udp.begin(hapticPort);  // Listen for haptic data
    Serial.println("[SYSTEM] UDP server started");

    // Configure GPIO pins
    pinMode(buttonA, INPUT_PULLUP);
    pinMode(buttonB, INPUT_PULLUP);
    pinMode(buttonSYS, INPUT_PULLUP);  // Used as wake-up button
    pinMode(buttonJOYCLK, INPUT_PULLUP);
    pinMode(buttonTRIG, INPUT_PULLUP);
    pinMode(buttonSQZ, INPUT_PULLUP);
    pinMode(joyXPin, INPUT);
    pinMode(joyYPin, INPUT);


    
    // Configure PWM for motor
    ledcAttach(motorPin, fixedFrequency, pwmResolution);
    hapticSignal();
    ledcWrite(motorPin, maxDuty);  // Ensure motor is off initially

    
    // Wait for START before proceeding
   waitForStart();
}

void loop() {
    unsigned long currentMillis = millis();


    // Handle keystrokes
    if (currentMillis - previousMillis >= sendInterval) {
        previousMillis = currentMillis;
        sendKeystrokes();
    }

    // Handle haptic feedback and check for STOP signal
    receiveHaptics(currentMillis);
}

void sendKeystrokes() {
    int buttonAState = digitalRead(buttonA) == LOW ? 1 : 0;
    int buttonBState = digitalRead(buttonB) == LOW ? 1 : 0;
    int buttonSYSState = digitalRead(buttonSYS) == LOW ? 1 : 0;
    int buttonJOYCLKState = digitalRead(buttonJOYCLK) == LOW ? 1 : 0;
    int buttonTRIGState = digitalRead(buttonTRIG) == LOW ? 1 : 0;
    int buttonSQZState = digitalRead(buttonSQZ) == LOW ? 1 : 0;

    int joyXValue = analogRead(joyXPin);
    int joyYValue = analogRead(joyYPin);

    char joyXFormatted[5];  // Buffer for formatted joystick X value
    char joyYFormatted[5];  // Buffer for formatted joystick Y value
    sprintf(joyXFormatted, "%04d", joyXValue);
    sprintf(joyYFormatted, "%04d", joyYValue);

    String packet = String(controllerType) + String(buttonAState) + String(buttonBState) +
                    String(buttonSYSState) + String(buttonTRIGState) +
                    String(buttonSQZState) + String(joyXFormatted) +
                    String(joyYFormatted) + String(buttonJOYCLKState);
    
    udp.beginPacket("255.255.255.255", localPort);  // Broadcast to all devices
    udp.print(packet);
    udp.endPacket();
    Serial.println("Sent: " + packet);
}

void receiveHaptics(unsigned long currentMillis) {
    int packetSize = udp.parsePacket();
    if (packetSize) {
        int len = udp.read(incomingPacket, sizeof(incomingPacket) - 1);
        if (len > 0) {
            incomingPacket[len] = '\0';
        }
        Serial.printf("[UDP] Received: %s\n", incomingPacket);

        // Check for STOP signal
        if (strcmp(incomingPacket, "STOP") == 0) {
            Serial.println("[SYSTEM] STOP received! Entering deep sleep...");
            goToDeepSleep();
        }

        // Ensure the packet starts with the correct controller identifier
        if (incomingPacket[0] == controllerType[0]) {
            int dutyCycle, duration;
            if (sscanf(incomingPacket + 1, "%3d%3d", &dutyCycle, &duration) == 2) {
                dutyCycle = constrain(dutyCycle, minDuty, maxDuty);
                ledcWrite(motorPin, dutyCycle);
                Serial.printf("[HAPTIC] Motor ON - Duty Cycle: %d\n", dutyCycle);

                // Start timer for motor duration
                motorEndTime = currentMillis + duration;
            }
        }
    }

    // Turn off motor after duration
    if (currentMillis >= motorEndTime) {
        delay(20);
        ledcWrite(motorPin, maxDuty);  // Turn off motor after duration ends
    }
}
void hapticSignal() {
    // Turn motor on
    ledcWrite(motorPin,15);  


    delay(100);

    // Turn motor off
    ledcWrite(motorPin, minDuty);
    delay(100);
}

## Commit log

2024-12-07 Config files added
    [openglovesconfig.txt]
2025-01-05 Arduino Core header added
2025-01-05 Add VR firmware rules and testing script for button state simulation
2025-01-05 Refactor button state handling and joystick input in NeoGrip firmware; remove obsolete rules file
2025-02-26 stop motor logic added + example haptic ino file
2025-03-13 Update ESP32 IP address and improve haptic feedback handling
2025-03-15 Add complete test scripts for ESP32 communication and haptic feedback
2025-03-23 Enhance controller connection handling and update button mappings
2025-04-02 Removed old files used for development
    [NeoGrip-L.step]
2026-03-07 feat: Implement NeoGrip proxy to bridge ESP32 controller input and haptic feedback with ALVR.
2026-03-16 chore: remove legacy driver
2026-03-16 fix: Add timeout handling for UDP socket to allow graceful shutdown
2026-03-16 fix: Implement thread-safe access to connected controllers and improve shutdown handling
